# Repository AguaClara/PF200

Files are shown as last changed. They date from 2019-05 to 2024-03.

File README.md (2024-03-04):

# Prefabricated-Pilot-Plant
Working on optimizing and redesigning the PF300 Plant.

[Data: constantly updated during plant operation](https://drive.google.com/drive/folders/15Q-oahdi-_HOuTjkzV-ZeO8t-d6P-ldm?usp=sharing)

[OnShape](https://cad.onshape.com/documents/c2d1f86405270e814e117305/w/5a99281e258edb48b9d633f5/e/6bae3d77db5722cca1e4684c)

**Spring 2024 Team**

Jiaming Yuan jy729@cornell.edu

Ari Schor aes392@cornell.edu

Anjali Asthagiri aa2549@cornell.edu

Claire Wang cyw34@cornell.edu

**Fall 2023 Team**

Sarah Bae ssb238@cornell.edu

Joshua Luoma jjl364@cornell.edu

Kayla Stephenson ks929@cornell.edu

Ari Schor aes392@cornell.edu

Jiaming Yuan jy729@cornell.edu

Anjali Asthagiri aa2549@cornell.edu

[Fall 2023 Report](https://docs.google.com/document/d/e/2PACX-1vT9NayLwSj0DSO6I6zIm8iFLQtal2snJDCT8Y99-VTBxyXMKy_upGpKFzNsSaJLsYfuqjPXhcydjL0X/pub)

**Summer 2022 Team**

Isabel Crovella isc25@cornell.edu

Sarah Bae ssb238@cornell.edu

[Summer 2022 Report](https://github.com/AguaClara/PF200/blob/5bb9a7f38fa5151b12aef5d702b937e5a5cea816/PF200_Summer_2022_Final_Draft.ipynb)

**Spring 2021 Team**

Sandra Cangelosi sc2749@cornell.edu

Son-Jay Lake svl24@cornell.edu

Melissa Louie ml897@cornell.edu

Lynn Shin ms3244@cornell.edu

[Spring 2021 Report](https://github.com/AguaClara/PF200/blob/master/Spring%202021/PF200_Report_Spring_2021.ipynb)

**Spring 2020 Team**

Whitney Denison wwd23@cornell.edu

Ashley Zeng az342@cornell.edu

Sandra Cangelosi sc2749@cornell.edu

**Fall 2019 Team:**
[Mid-semester Symposium Presentation](https://docs.google.com/presentation/d/1beXxfFk0Zb6vNhiRZd7WTKsvpil8FLFxB8vfp_9dHnY/edit?usp=sharing)

**Summer 2019 Team:**

Marcin Sawczuk mas874@cornell.edu

Kevin Sarmiento ks2255@cornell.edu

Ian Cullings idc25@cornell.edu

Yitzy Rosenberg yyr2@cornell.edu

[Symposium Presentation](https://docs.google.com/presentation/d/14-7EX47XN8-9KOKcPPQAOfRzo7gDOhDvY8mLLPdoe-Y/edit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)

[Final Presentation](https://docs.google.com/presentation/d/1NT3kG8-FQKytqtTQstRGDQaPQnel-frj4UgSt9LlMlI/edit?usp=sharing)

[Final Report](https://colab.research.google.com/github/AguaClara/Prefabricated-Pilot-Plant/blob/master/Summer2019_Report_2.ipynb)

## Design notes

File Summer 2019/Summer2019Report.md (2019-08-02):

sedimentationweir# Prefabricated Pilot Plant, Summer 2019
#### Ian Cullings, Yitzy Rosenburg, Marcin Sawczuk, Kevin Sarmiento
#### August 2nd, 2019

##Abstract

The AguaClara PF 300 is a fully functional small scale water treatment system currently utilized in Honduras.  It's smaller scale makes it ideal for villages where the need is still significant, but it is not economical to build full scale built plants.  While the plant currently operates, there are significant problems in the design which need to be resolved to further improve treatment and allow for more to be built.  Additionally, the PF 300 serves as a perfect model for typical water treatment processes, including flocculation, sedimentation, and filtration, and thus data collected from this system can be used to study these processes and inform future design decisions.  The goal of the team this summer is twofold: collect water quality data from the plant, and use this information on new design projects for the system.  

## Introduction

The AguaClara PF 300 system (previously known and the 1 LPS plant or the Plantita) is a small scale, built system which can treat water at a rate up to 0.66 L/s.  The system was designed using AguaClara's principles, and thus models the built water treatment plant in the key areas:
* Gravity Powered: The entire plant is entirely powered from differences in hydraulic head from the inlet and outlet.  The design does not utilize electricity or mechanical parts, pieces that cause many problems when utilized in the field
* Built in place: The plant does not use any moving parts, and thus is functional from installation, reducing needs for maintenance and extending the operational life
* Utilizes hydraulic flocculators: Similar to AguaClara's built in place plants the PF300 uses a hydraulic flocculator to obtain the desired collision potentials for efficient flocculation
* Floc Blanket technology: The sedimentation tank of the PF300 creates an effective floc blanket just like the built in place AguaClara plants
* Stacked Rapid Sand Filters: The PF300 has a similar stacked filter design to that of built in place plants with the distinction that filter in this case is enclosed and must be under negative pressure

The main objectives for the summer were:
* Restore PF 300 to full operation and install Stacked Rapid Sand Filter
* Install lab bench and computer and connect all sensors for data collection
* Redesign of PF 300 components to improve operation quality and make construction easier

## Literature Review and Previous Work

The first PF 300 system was designed during Spring 2016 and built during Summer 2016 by a group of students and engineers on Cornell's campus.  Future teams tested the system and worked to streamline the fabrication process, after which the first system was sent of Honduras for testing in the field.  In 2017 another system was fabricated at Cornell and tested with the full treatment process, which continued into Spring 2018.  

In Fall 2018, there was no subteam specifically focused on research with the PF300.  Instead, Meng student Zoe Maisel focused her thesis on developing the PF300 system for usage in the United States.  Part of her project was moving the PF300 system from the DeFrees Hydraulic Lab at Cornell to the Cornell Water Treatment Plant.  There it was connected to the plants influent line, allowing for parallel operation of both systems for comparison.  She also wrote a detailed thesis comparing the PF300 system with typical water treatment systems within the US [(Maisel, 2018)](https://github.com/AguaClara/Prefabricated-Pilot-Plant/blob/master/Lit_Review/Maisel-High_Rate_Processes.pdf).

As part of the CEE 3520 course at Cornell, a few student groups developed design projects around the PF 300 which formed the basis for the design work this summer.  Inspiration for the plastic honeycomb piece for plate settlers came from "TuBe Or Not TuBe: A Comparison of Alternative Plate and Tube Settler Geometries" [(Connely et. al. 2019)](https://github.com/AguaClara/CEE3520/blob/master/Previous%20Final%20Projects/2019S/HummusHummus_Final_Report.md).  The design idea and code was sourced from the "Flocculatorita" project [(Blahut et. al. 2019)](https://github.com/AguaClara/CEE3520/blob/master/Previous%20Final%20Projects/2019S/Flocculatorita.md).  And the redesign of the sedimentation tank was based on work done in "Straight singular sedimentation tank for a modular plant" [(Guardado et. al. 2019)](https://github.com/AguaClara/CEE3520/blob/master/Previous%20Final%20Projects/2019S/LaMeraChimba_4L_per_S_sed_tank.md).  

Research that inspired the current questions on particle removal was done by Casey Garland.[(Garland, 2016)](https://github.com/AguaClara/Prefabricated-Pilot-Plant/blob/master/Lit_Review/Garland%26Monroe_Failure_modes_of_a_floc_blanket.pdf) [(Garland, 2017)](https://github.com/AguaClara/Prefabricated-Pilot-Plant/blob/master/Lit_Review/Garland%26Monroe_revisiting_hydraulic_flocculator_design.pdf).

## Methods

# Project One: Sensors and Data Acquisition

The first project for the summer is installing a number of sensors to collect data on the effluent from the PF 300.  Five sensors were installed: two Chemtrac PC6 particle sensors, one Chemtrac UV254 organics sensor, and two HF Scientific Turbidimeters.  One turbidimeter, one particle counter, and the organics sensor take samples from the effluent of the sedimentation tank (known as settled water), and the other turbidimeter and particle counter take samples from the outlet to the filter box.

All five of these sensors are connected to a main computer on the lab bench through Modbus RS485.  Modbus allows connection to up to 255 different sensors, each with a differing address.  Therefore, the team was able to wire each sensor together in a "daisy chain," with one single wire going into from the HydroAct through an adapter and connected directly into the computer.  

Effluent quality data is logged directly with ProCoDa, a process control software developed by Dr. Weber-Shirk.  The method file for data collection is available [on Github](https://github.com/AguaClara/Prefabricated-Pilot-Plant/blob/master/Data/Method_Files/Plantita_2.pcm).  The code for this, written by Dr. Weber-Shirk, is very similar to that used in the lab to connect to the turbidimeters.  Each device is assigned an address in the network, and then each data input (for example, total particle count, or the UVA reading) is assigned a data address from that device.  ProCoDa constantly samples these and saves them into an excel datalog, which is then imported from that computer through google drive to the cloud.  [You can view the data in real time here!](https://drive.google.com/drive/folders/15Q-oahdi-_HOuTjkzV-ZeO8t-d6P-ldm?usp=sharing)

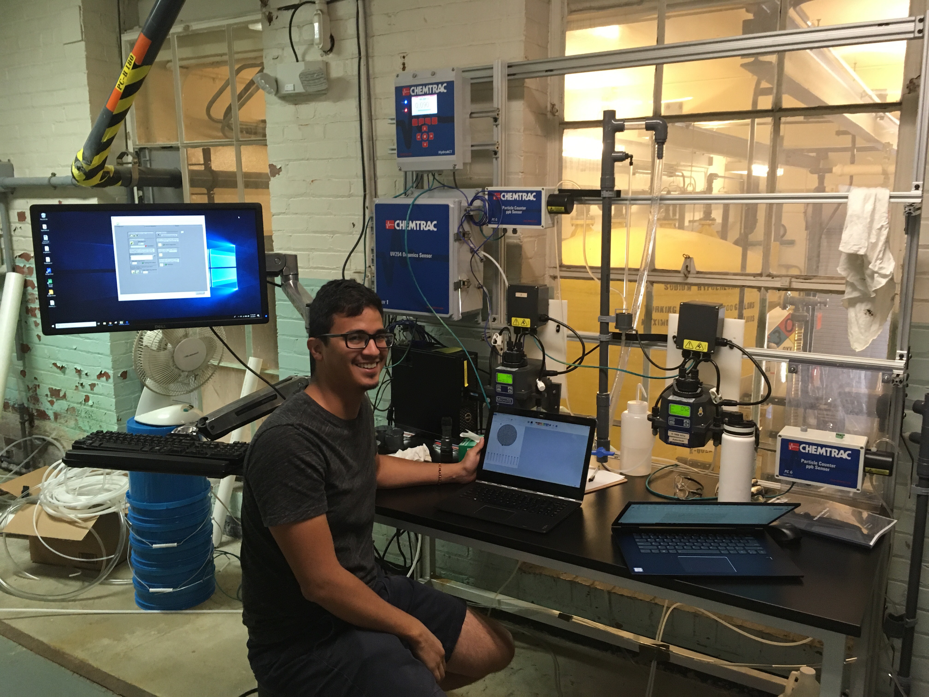
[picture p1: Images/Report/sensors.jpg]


**Figure 1:** The full sensor setup at the lab bench

This data will be used for two purposes.  The first is to further research on floc blanket function and efficiency.  Past research by Casey Garland showed that particle removal efficiency of the floc blanket was first order with respect to depth, but then eventually tapered off to a flat line with no further particle removal.  [This video](https://github.com/AguaClara/Prefabricated-Pilot-Plant/blob/master/Lit_Review/sedimentation.mp4) shows one experiment that gave this result.  This information is part of the justification for the design floc blanket height.  However, current theories in particle interactions within floc blankets suggest that smaller particles are being preferentially removed from the floc blanket, while larger particles become more easily sheared off and escape.  In an upflow system like the floc blanket, there is a stagnation point under suspended particles.  If a smaller particle follows the streamline and hits this point, it can easily collide and stick to this particle.  However, if a particle follows another streamline, the boundary layer around the particle prevents collisions.  This rapid flow around the particles also can shear larger particles off and allow them to escape.  This is shown in Figure 2 below.  

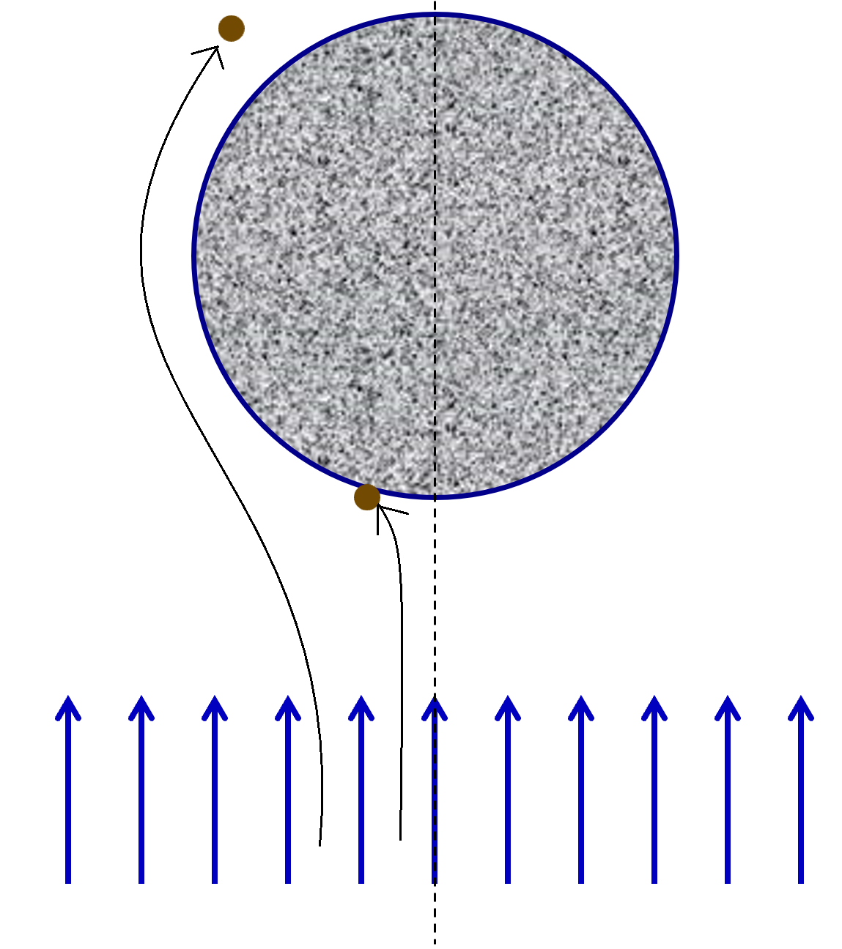
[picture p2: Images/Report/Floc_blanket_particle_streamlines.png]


 **Figure 2:** The large floc is suspended in the floc blanket and has a point of stagnation that allows smaller primary particles to effectively collide if their approach is from the correct orientation, streamline on the right. However if the particle is too far off the side then a collision will not occur, left most streamline.

Since turbidimeters are unable to measure turbidity from small particles well (since they reflect significantly less light than larger ones) it is possible that previous experiments did not capture this result well.  Thus, data collection on particle size distributions will provide a more accurate picture of the types of particles escaping the floc blanket.

If this theory is true, it suggests that increasing the height of the floc blanket will actually be beneficial, as smaller particle removal will increase.  Since these particles are very difficult to remove, even within the filter, this result would be very positive towards increasing the treatment capability of AguaClara plants of all scales.

The other important parameter to collect for this experiment is the height of the floc blanket.  Unfortunately, since the PF 300 system is not transparent, there is no way to visually inspect this.  The only directly visible measure is through the floc hopper, where flocs can be seen escaping.  This only occurs when the floc blanket begins to grow above the height of the floc hopper (the maximum height).

The team considered a number of possible sensors to detect height as a function of time, including installing electrical sensors inside, taking constant measurements from the sampling ports on the side of the plant, and taking measurements by lowering a probe in from the top of the plant.  All of these possibilities were eventually decided against, and the following methods were determined to be the most simple and effective:

1. Experiments with a typical rangefinder, pictured below, show that it can read the height from the top of the floc blanket.  Thus, by continuously running a rangefinder affixed to the top of the plant, and shining the laser between the plate settler, we can measure the distance from the rangefinder to the top of the floc blanket, and using simple geometry we can convert this into the height of the floc blanket.  The current rangefinder in use works but does not connect to a computer, so measurements must be made manually.  Note that the rangefinder doesn't work if water is too turbid that the particles reflect the laser, but the team found that typically within ~30 minutes after startup turbidity lowered enough to make accurate measurements.

2. When the plant begins operation after being fully drained, the floc blanket height can be assumed to be 0.  Once significant levels of flocs are observed leaving the floc hopper, the floc blanket can be assumed to have reached it's maximum height.  In between, the relationship between floc blanket height can be approximated as linear.  By measuring the time flocs begin to leave the floc hopper, the slope of this line can be determined.

Research is ongoing into the best method to measure this.

The second purpose for data collection is to provide water quality data over long term usage of the PF 300, which can justify the efficacy of the system, and provide direct comparison with other conventional water treatment systems like the Cornell Water Filtration Plant.  While PF 300 systems are currently only utilized in Honduras, there is lots of evidence that a similar system would be very useful in smaller communities in the United States, or other areas.  One such example is Native American reservations, which have had many issues with water quality and supply in the past.  Team members have talked with officials from the US Indian Public Health Service and are beginning to explore the need for these systems there.

# Project Two: Filter Assembly

Previous teams designed and built the Enclosed Stack Rapid Sand Filter and transported it to the Cornell Water Filtration Plant. This summer the team worked to connect it to the PF300 and make the necessary changes to ensure that it operates.

## Assembly

The first task to connecting the filter was to find a way to divert the settled water to the filters entrance tank. The sedimentation tank's effluent leaves through a 3 inch PVC pipe that then is diverted to the CWFT's rapid mix unit for treatment. This technique allows us to run our experiments with the same water that the CWFP uses and also ensures that our experiments won't compromise the CWFP's treated water quality. A tee and two ball valves were installed on the sedimentation tank's exit line to allow the settled water to be selectively diverted either to the filter or to waste.
In addition to that change we took the opportunity to add a flow weir to the sedimentation tank. This allowed us to raise the water level inside of the sedimentation tank and ensure that the exit launder was fully submerged at all times with about an inch of water above it.

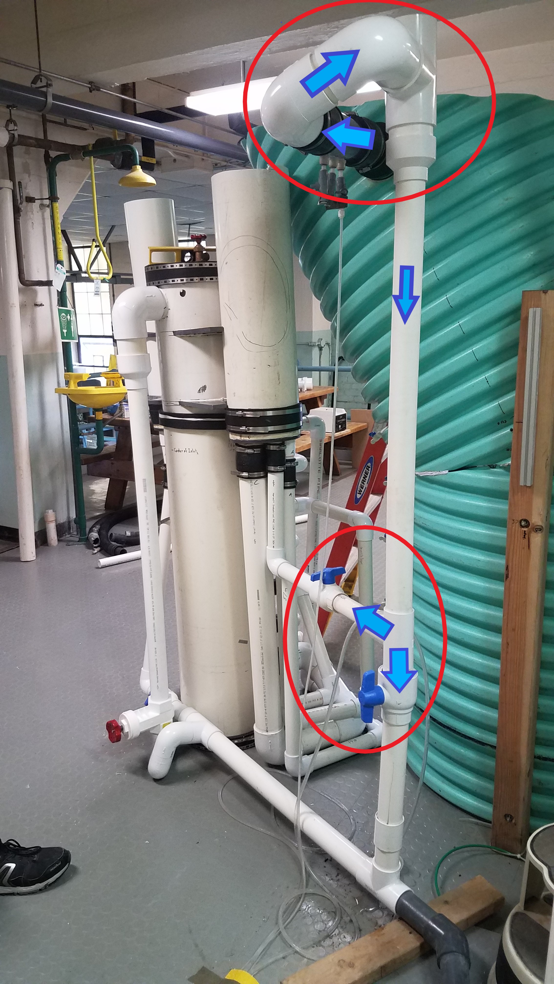
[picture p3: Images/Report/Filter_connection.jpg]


**Figure 3:** The flow weir was made out of two 3 inch PVC elbows and can be seen in the top circle. The settled water flows down the main pipe and can be diverted either to the filter, to the left, or to waste, straight down.

As can see in figure 2, when the ball valve in the vertical pipe is closed and the valve in the line feeding the filter is opened, settled water will go through the filter and be treated further.

## Filter Entrance Tank

Settled water from the sedimentation tank first arrives to the entrance tank of the filter, right most tank in figure 3.

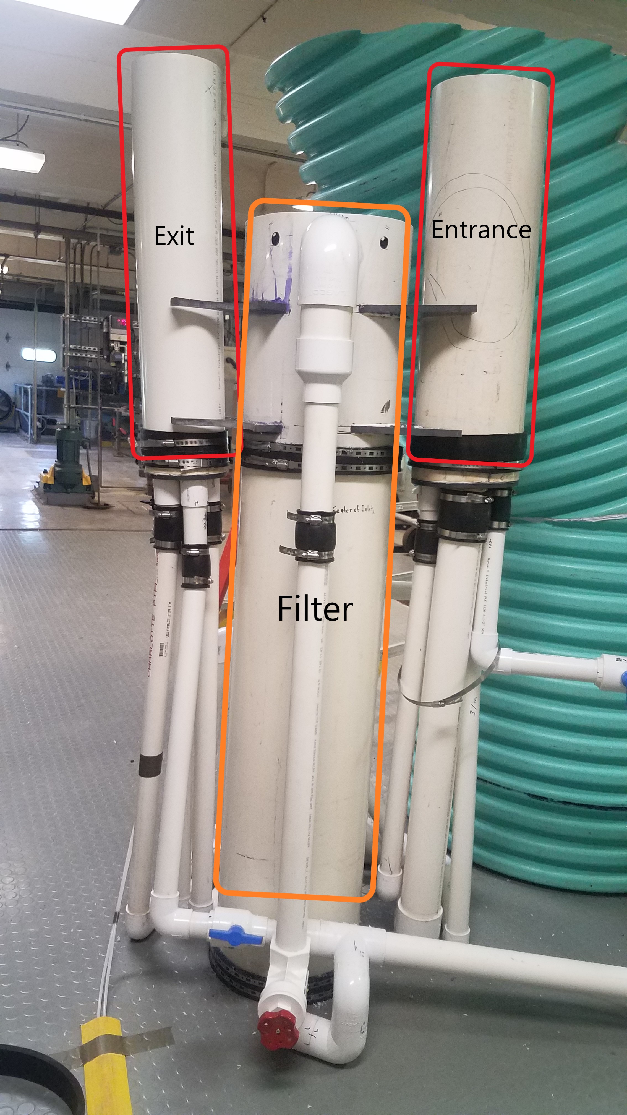
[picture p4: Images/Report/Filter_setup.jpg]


**Figure 4:** The three main compartments of the filter are the entrance tank, sand filter body, and effluent tank.

Once the settled water enters the tank, the flow gets divided into four separate PVC pipes which feed the filter at four different elevations. The distribution of flow can be seen in figure 5. Additionally, the entrance tank has 16.5 cm pipe stubs on three of the four pipes leading to the filter. This allows the entrance tank to function properly during filtration and also during backwash. During filtration settled water needs to go through all of the pipes, therefore the water level in the entrance tank needs to be high enough to allow flow into the pipe stubs. However, during backwash the flow needs to go through the larger diameter pipe, labeled in red in figure 4. This pipe attaches at the lowest point in the filter tank and because of that is responsible for fluidizing all of the sand in the tank during the backwash process. The pipe stubs ensures us that during backwash all of the flow goes through the bottom most pipe.

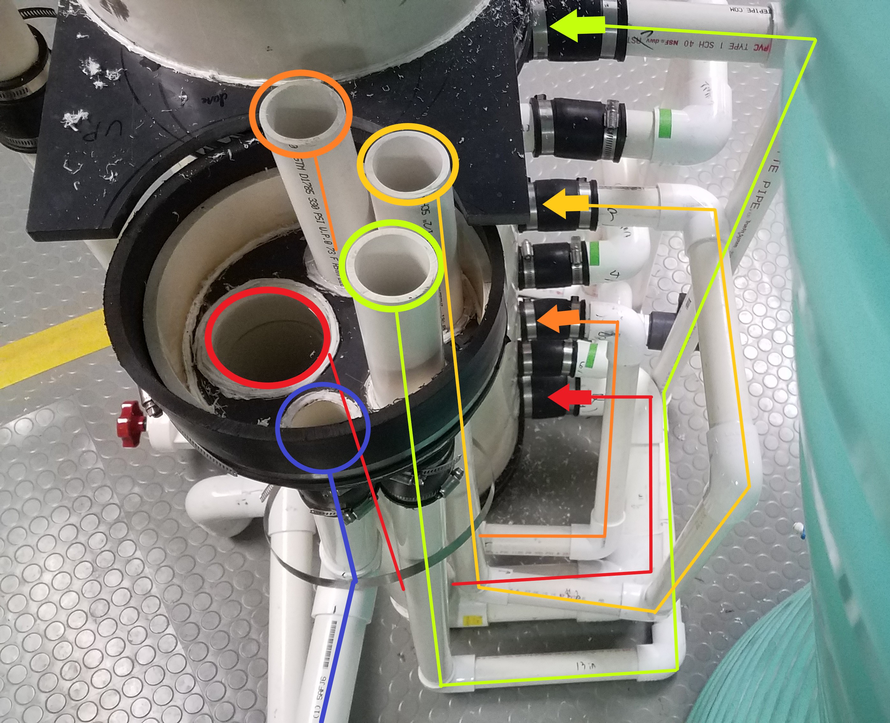
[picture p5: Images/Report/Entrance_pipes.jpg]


**Figure 5:**  Flow directions through the inlet pipes within the filter.

# Project Three: System Redesigns

## Flocculator

## Sedimentation tank

## Filter

This summer was the first time a EStars filter had ever been fully assembled and tested in a treatment process.  As with any complicated system, there were numerous problems that come up, and further design and testing is needed before this system can be implemented in the field.  The major problem identified with this system was the escape of sand through influent and influent pipes.

Escape of sand through the influent pipes was observed many times during operation, often due to errors in running the system.  The filter is designed such that sand should never escape the inner tank, as the upflow velocity should be too low to lift the particles all the way out the siphon system.  The following processes showed loss of sand (either through the siphon to effluent, or into the influent pipes):

* Running backwash without first opening the effluent line.  Backwash is a very fine balance of pressures, and if one side is over or underpressurized it will not work properly.  Thus it is very important that whenever backwash is run the effluent line is open throughout the entire process.
* Closing the backwash value quickly.  When backwash is running, water is flowing through the siphon very quickly due to the negative pressure.  If you close the valve and stop this process too quickly, it can "shock" the system and cause water to flow backwards through the pipes to return to the static head.  When ending backwash you must close this valve very slowly and gradually, at roughly 1 turn every 10 seconds.
* Opening flow into the filter without stopping flow to effluent.  There are two valves at the junction after settled water, one controls flow to the drain, and one controls flow into the entrance tank of the filter.  Typical operation is to open flow to the filter first then stop flow to drain, to prevent flooding.  However is the influent tank is left full of water, this water will flow backwards to lower head when the valve is open, which can pull sand from the inner tank.  Thus, whenever you reconnect the filter you must first close the valve to drain, allow water to rise to about the level in the entrance tank, then open the valve to the entrance tank.  

The team also observed significant amounts of sand within the exit tank, and even some in the turbidimeter reading from the exit tank. This means that sand is escaping the inner tank to effluent, which the slotted outlet pipes are designed to prevent.  This suggests that some of all of the slotted outlet pipes were designed incorrectly, and that sand can escape through these pipes.  

While a few different possibilities were considered, this shows a clear failure in the filter, and means that the filter must be either be repaired or remade completely.  Work is ongoing, but the current plan is to assemble a new filter, using the design of "gravity exclusion zones" by [Stars FINE](https://github.com/AguaClara/StaRSFine) in Spring 2019.

# Operation Manual

To turn the PF 300 on and begin collecting data:

1. Ensure all valves are open and flow is not blocked anywhere
2. Turn the main pump switch from OFF to HAND to begin flow within the plant
3. Turn on the peristaltic pump on the floc hopper and ensure the valve coming off the floc hopper is opened
4. Turn on the HydroAct and both turbidimeters by plugging them in
5. Turn on the main computer on the lab bench and log in on the generic AguaClara account, en-ce-ac
6. Open ProCoDa and check that the "Plantita_2" method file is being read
7. Data will automatically be collected and saved by ProCoDa, and uploaded into the cloud by Google Drive

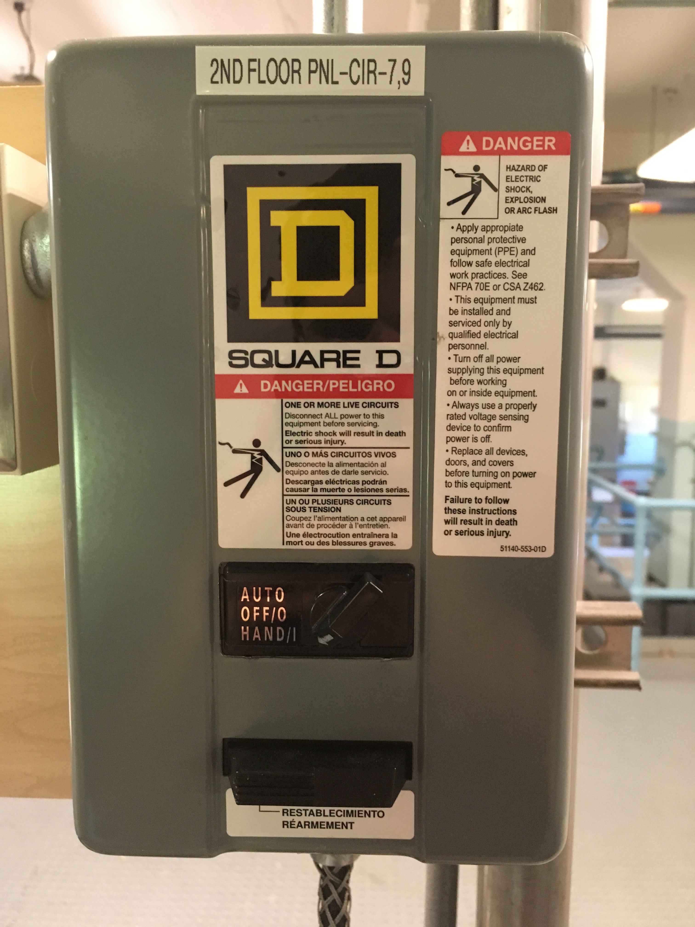
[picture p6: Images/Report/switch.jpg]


**Figure 6:** ON/OFF switch for the pump

To pressurize the filter (necessary whenever there is air within the inner tank, such as after removing the lid for repairs):

1. Open the valve on top of the filter to allow air to escape during process
2. Close the outlet valve to ensure no flow is leaving the filter
3. Water will begin to flood and raise the level within the influent tank.  Wait until water comes out of the top valve of the influent tank, then quickly close the top valve and open the effluent.  
4. Sometimes due to the flow restrictions by the sand bed, water level will rapidly rise in the entrance tank but will not raise in the inner tank for a while.  In this case open the valve off the effluent from the sedimentation tank partially to prevent the entrance tank from overflowing, and wait until water leaves the top valve of the inner tank
5. When you open the effluent you should hear a gurgling sound and observe flow being pulled into the effluent pipe.  This means the inner tank is pressurized and filter is operating correctly

To run backwash in the filter:

1. Backwash should be run whenever headloss in the entrance tank causes water level to rise significantly, typically daily.  Whenever you change the sand within the tank, you should also run backwash first to remove any particles that may have built up
2. Ensure inner tank is pressurized and there isn't air inside
3. Open the red backwash valve.  You should hear water being pulled through this pipe to the drain
4. Ensure that water level in the influent tank drop to below the pipe stubs on the entrances to the other inlets.  When backwash is operating fully, water should only be flowing from the backwash line
5. After backwash is complete, **slowly** close the backwash valve.  Once the valve is completely closed backwash should end and filter operation should resume as normal.

To flush pipes (cleaning sand from within):

1. Insert pipe plugs on all pipes except backwash line
2. Start backwash cycle as normal.  Run with just backwash line for 1-2 minutes
3. Open plug for lowest influent line (leftmost pipe).  Plug backwash line and allow water level to rise
4. If the water level is too low (just above the pipe stub) air will also be sucked in through the line.  To prevent this, partially block the pipe stub and allow water level to raise ~6 inches above the pipe stub entrance.  We used our fingers to block this, although this is not recommended as the suction is very strong.  
5. Swap the plugs and repeat this process for the other two pipes.  Whenever you switch flows ensure water level is high enough that air doesn't enter the pipes
6. Once you have flushed all pipes break backwash and remove all plugs.  If sand was removed from the pipe the sand level should be observably higher

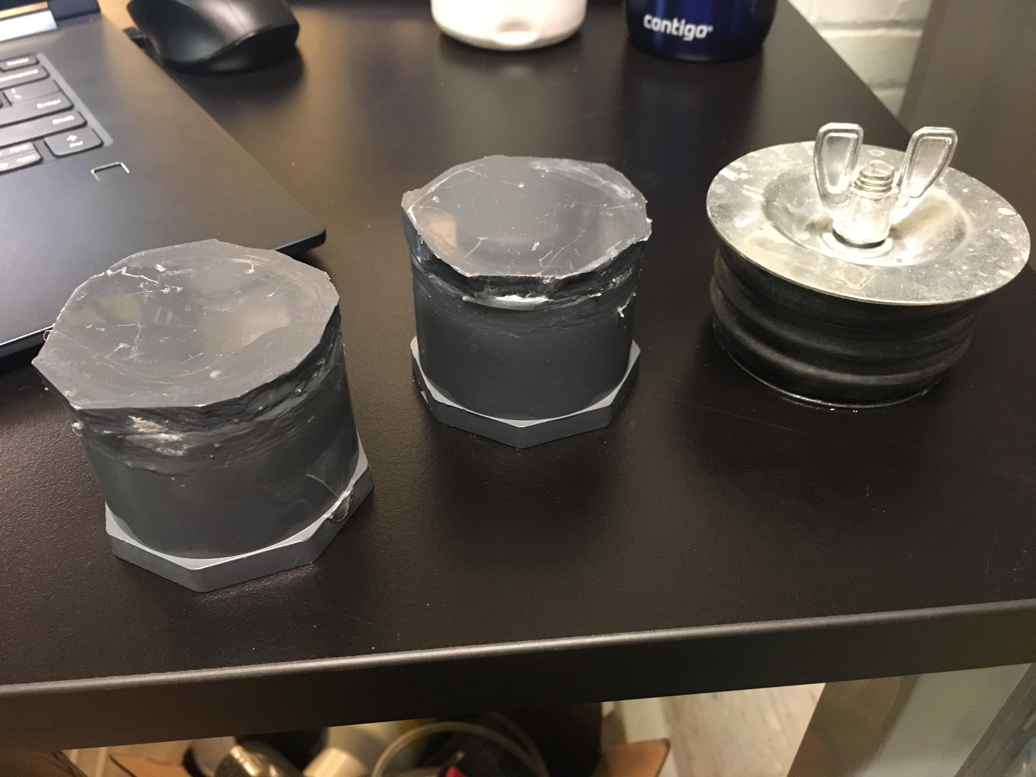
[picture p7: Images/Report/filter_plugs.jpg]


**Figure 7:** Plugs used to force flow through one inlet

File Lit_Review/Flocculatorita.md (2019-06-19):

#The Flocculatorita

####By The Water Tzars: Nina Blahut, Lily Falk, Marcin Sawczuk, Yitzy Bitzyspider


<p align="center">

*Figure :). Floco, the flocculatorita mascot.*

## Introduction and Background

The prefabricated plants (PF300) are a subset of AguaClara plants designed for small communities who may not have the resources to finance, or the population to require a built-in-place plant. There are currently 3 in Manzaragua, 1 in Cuatro Comunidades, 1 near Copan (Honduras) in use, and one at Cornell's Water Filtration Plant in the testing phase. Built-in-place AguaClara plants are housed in buildings with separate areas for flocculation, sedimentation and filtration. In contrast, the PF300 occupy considerably less space, as the plant is only two and a half meters tall.

PF300 plants have made it possible for small communities to receive clean water, and have served as an addition to increase the capacity of built-in-place AguaClara plants, as they were added in parallel with the main treatment process chain.

The low population density and small community size in areas that use PF300 plants has led to difficulty with employing plant operators. The PF300 plants provide water to fewer people, however require the same degree of monitoring as a full scale plant. As a result, delegating a plant operator has created a larger burden on these communities. An ideal system for an individual to check on the plant for coagulant dosing and general running issues has not yet been well established.

The PF300 flocculator is in need of improvement to increase flexibility of the design. Currently the flocculators are made out of 3" PVC pipe. High cost of the PVC fittings make it expensive to build flocculators according to this design for higher flow rates or residence times. This is because the change would require switching to bigger pipe diameters. Representatives from AguaClara’s partner organization in Honduras, Agua Para El Pueblo (APP), have expressed interest in a larger flocculator. A longer residence time would provide operators with more time to respond to high turbidity events to prevent the dirty water from reaching the sed-tank and disturbing the floc blanket which causes long term decrease of the effluent water quality. Moving forward, there is desire for the portable plants to come in multiple sizes. Hopefully, this would lead to a more cost efficient design of the prefabricated plants in various sizes.

The Water Tzars have worked to design a new flocculator which will be more flexible and scalable than the current system. The group has envisioned flocculation within a large diameter pipe divided into channel with baffles and expansions enabling complex flow within the pipe that would lead to successful floc formation. Moving forward the group will consider alternative materials for the sheets that will work as baffles.


<p align="center">

*Figure 1. Sample Flocculatorita design.*

## Design Process

The design process for the small hydraulic flocculator is based on the AguaClara top down design approach (presentation 2, slide 20), but made slight alterations to make it possible for our flocculator to fit into a large PVC pipe or HDPE tank. We then modified the AguaClara Flocculator source code to come up with a class that designs a small flocculator that can be housed inside of a large PVC pipe, which we have named a "flocculatorita". The collision potential ($G_{CS} \theta$) for our design is constrained to 37,000, which is based on the collision potential that is currently used in AguaClara plants (2). Our design is also constrained to a total headloss of 40 cm. This constraint is also based on the head loss which is currently used in AguaClara flocculators (3). Next, the height of the flocculator is constrained to 2 meters. This is to ensure that the flocculatorita is not taller than a sedimentation tank. This logic is also borrowed from AguaClara source code (3). Lastly, our design is constrained by the available diameters of large PVC pipes that can be used as a tank for our flocculatorita.

The first step in AguaClara's top down design approach for the flocculator is to calculate the required flocculator volume. We used the same process as defined in the AguaClara Flocculator source code to determine the required active volume in our flocculator (3). To do so, the AguaClara flocculator class first calculates the Camp Stein velocity gradient (average velocity gradient) using the following equation:

$G_{CS} = {\frac{gh_{\rm{L}}}{\nu G\theta}}$

This calculation is done below in the property "vel_grad_avg." Then, the average velocity gradient is used to calculate required residence time in the flocculator by dividng [spelling] target collision potential by the calculated average velocity gradient:

 $\theta = {\frac{ G\theta}{G_{CS}}}$

  This calculation is carried out in the property "retention_time." Finally, the calculated retention time and user-defined flow rate is used to determine the required flocculator volume (calculation is performed in the class "vol"):

$\rlap{-} V_{floc} = {\theta}{Q}$

After calculating the necessary active volume in our flocculatorita, we determined the necessary active cross sectional area by dividing the volume by the height of the flocculator:

$A=  \rlap{-} V_{floc}/ H_{floc}$

We made some simplifying assumptions to decide which size PVC pipe was appropriate to use as a tank for the flocculatorita. We assumed that the active space inside of our tank would be the largest square that could be housed in a cross section of the PVC pipe tank, to avoid the complication of different sized/shaped flow channels. This simplifying assumption results in excess dead volume, but we hope in the future to come up with an algorithm to optimize the cross sectional area of the pipe to minimize that dead volume. Using our simplifying assumption, we found the side length of the largest square, and used Pythagorean's Theorem to find the length of the diagonal of the square. This length is the necessary diameter of the PVC pipe tank:

$D_{tank}=\sqrt{2*A}$


<p align="center">

*Figure 2. Top view showing the original design idea. This design was based on a square active area housed within the circular PVC pipe.*

These calculations are carried out in the property "min_diameter_tank." Then, the code selects the PVC pipe diameter that is closest to and larger than the calculated minimum from an input array of available PVC pipe diameters in the property "design diameter tank."

After selecting a PVC pipe to use as a tank, we solved for the side length of the square that would fit inside of the chosen pipe using the Pythagorean Theorem:

$L=\sqrt{\frac{1}{2}D_{tank}^2}$

This calculation is performed in the property "channel_L" because the length of one side of our square is analogous to the channel length in a regular AguaClara flocculator.


<p align="center">

*Figure 3. Top view showing example channels
 (three chosen for picture arbitrarily).*

The next step was to determine baffle spacing and channel width. Since there was not a clear constraint on either, we decided that we would allow the user to input the number of channels, and use that to determine channel width:

 $W_{channel}=L_{channel}/n_{channel}$

 A benefit to this method is that it creates channels with equal widths and maximizes the space used within the square cross section of active space. This calculation is included in the property "channel_W."

 
 <p align="center">

 *Figure 4. Top view with channels and baffles (number of each chosen arbitrarily for drawing).*

Next, we used the AguaClara source code to determine the maximum distance between expansions for the largest allowable H/S ratio (3). The equation used in that calculation is:

$H_{e_{Max}} = \left[ \frac{K}{2 \nu G_{CS}^2} \left( \frac{Q \Pi_{{HS}_{Max}}}{W_{channel}} \right)^3 \right]^\frac{1}{4}$

Next, we determined the number of flow expansions per baffle space with the calculation (2):

$n_{expansions} = {\rm ceil}\left( \frac{H}{H_{e_{Max}}} \right)$

This calculation used included in the property "expansion_n".

Our next step was to determine the baffle spacing. We did so using the AguaClara source code. The property is named "baffle_S" and it calculates baffle spacing using the equation:

$S = \left( \frac{K}{2 H_e G_{CS}^2 \nu } \right)^\frac{1}{3} \frac{Q}{W_{channel}}$

The next property in the Floccuratorita class determines the number of obstacles per baffle. This is done using the AguaClara source code, and it is simply one less than the number of expansions per baffle space, since one expansion is taken care of with the 180 degree bend (3).

The next property, "obstacle_size" determines the size of the obstacles, so that the energy dissipation rate for flow expansions caused by the obstacles and the 180 degree bends are equal. The Vena Contracta for a 180 degree bend is approximately 0.384 (presentation 1, slide 7), so we solved for the obstacle length, given the baffle spacing that would result in the same Vena Contracta:

 $L_{obstacle}=S_{baffle}(1-\Pi_{VC})$

 We plan to fabricate these obstacles using half pipes.

Then, the property "baffle_n" calculates the number of baffles:

 $n_{baffle}=\frac{L_{channel}n_{channels}}{S_{baffle}}$

 For the cost comparison, we are including the following factors:
 1. Cost of the main tank
 2. Cost of the sheets dividing the tank into channels
 3. Cost of the baffles
 4. Cost of the half-pipes used as obstacles for the flow

We also included a property called "pi_sedtank_floc," which calculates the ratio of the sed tank diameter to the flocculatorita diameter if the sed tank's up flow velocity is 1 mm/s and height is 2 m. According to the conservation of mass, the flow exiting the flocculator must equal the flow going through the sed tank, which is equal to the cross sectional area of the sed tank times its upflow velocity. Therefore,

$A_{sedtank}=Q/V_{up}$

"Pi_sedtank_floc" uses that relationship to find the cross sectional area of the sed tank and then uses that to find the diameter of the sed tank. Finally, it divides the diameter of the flocculatorita by the diameter of the sed tank and returns that ratio. This function does not account for the fact that diameters are only available in discrete sizes.

## Cost Comparison
First, we decided to model a floculatorita that has a residence time of 1 minute and flow rate of 1 liter/second in order to make a reasonable cost comparison between our design for the flocculatorita and the current flocculator used for the PF300 plant. We did so by making a child class of the "flocculatorita" class with those adjustments. This child class is named "Floc_1_min_res" and is shown in the block of code below. Next, we used that class to get an estimate of the cost of the floculatorita, which would handle similar flow and have the same collision potential as the current PF300 flocculator.

### Cost Comparison Analysis

Based on our cost comparison, the flocculatorita is 1.606 dimensionless times the cost of the current flocculator. That being said, this estimate is an overestimate due to the fact that it utilizes US prices more than Honduran prices. Even with the additional price, the new design presents improvement over the old as it is more adaptable, and has potential moving forward.

# Future Work

### Adding the auxiliary equipment
Current design of the flocculator does not include the auxiliary components or manufacturing procedures. To make the design suitable for commercial deployment, it should include the following aspects:

  1. Method for fixing the PVC sheets to the wall of the tank. We propose using long pieces of PVC glued to the inside of the tank wall, which will create a slot for sliding in the PVC sheet. The slot could be then filled with the silicone gasket maker, in order to seal the connection.

  2. Tank bottom design, preferably allowing for disassembly for servicing. Tank should have a flat bottom, which will be supported by the concrete floor. Although it requires placing the flocculator inside the structures with a solid floor, the advantage of having a support structure beneath the tank and therefore not having to worry about supporting the water mass by the tank bottom exceeds potential complications. Flat bottom of the tank can be attached to the corrugated pipe using clamps or bolts holding onto the pipe corrugations. Bottom should be fitting with the slots similar to the ones on the walls, in order to ensure sealed connection with the PVC sheets. Silicone gasket maker can be also used for sealing the connection between the pipe and the bottom.

  3. Attaching an entrance tank/rapid mix unit and a chemical dosing system. In the current PF 300 design, rapid mix and the dosing system are separate units. However, in order to fully take advantage of the compact design proposed in this project, it might be beneficial to incorporate both of them in the flocculator structure. This way, the plant layout will become simpler and more robust, as the components will be protected from impact by the outer structure of the corrugated pipe. Moreover, the pipe itself will provide sufficient structural support for mounting the entrance tank a the chemical dosing system, without the need for additional structure.

  4. Connection to the sedimentation tank, with a valve providing option for separating the two units and additional drain lines at both sides of the valve, in case of need for draining either the flocculator or the sed-tank. Connection should be made through the hole at the bottom of the flocculator tank.

  5. In order for 4. to work, water has to flow in an order which would allow for draining the flocculator after removing the baffles, i.e. connections between the channels separated by the PVC sheets has to be made at the bottom of each sheet (similar to the concrete AC flocculators)

  6. Drain line for wasting the water from the flocculator can be simply added by making a hole at the top of the last channel, above the water level in the first channel. Closing the connection between the flocculator and the sed tank will result with raising the water level until it reaches the drain line, from which it will be wasted.

  7. Baffles can be made in a similar way to the ones currently used, as packets of the polycarbonate sheets with the half-pipe flow constrictions, which can slide into the channels.

### Maximizing surface area

With our current design we only utilize roughly 64% of the available surface area in the tank. This obviously  is very inefficient from a design and cost perspective. As the current cost comparison demonstrates approximately a .6 increase using the flocculatorita design, if space could be maximized by extending the channels, at a minimum utilized surface area would increase to 84% and cost would decrease by .6, making the flocculatorita a comparable if not preferable design.

 $\%_{utilization}=\frac{A_{tank}-A_{flocculator}}{A_{tank}}*100\%$


<p align="center">

*Figure 5. Comparison of the current design and future work's wasted volume in tank.*

 For future work, the challenge would be to update the code in such a way that it maximizes the effective area used for flocculation. This will have to take into account, among others, the following considerations:

  1. The *geometry* required to get the target velocity profiles necessary for flocculation to occur. Assuming extension of the channels to the edge of the tank, consideration must be taken regarding the differences due to the curvature of the tank and how these differences effect the flow and subsequently the relating velocity profile. It is recommended that one err on the side lower velocity profiles in the uncertain regions to ensure that at the very worst, already created flocs don't break apart.


<p align="center">

*Figure 6. Illustration of uncertainty regarding effective geometry differences to get target flocculating velocity profiles.*

  2. The flow from one channel to another and then out of the flocculator needs to be designed. Consideration on to perhaps using the space in the wasted volume sections or using the ends of the channels where there is uncertainty about the flow geometry as the channel connections.

  3. The maximum angle given from the line created by tracing the first channel's uppermost tip to the last channel's lowermost tip and the first channel's line needs to be created taking into account wasted volume, usable flocculating compartments (that are dependent on target velocity geometries), channel connections, and inflow and outflow pipes.

### Cost comparison future work

The current cost estimate for the flocculatorita is likely much higher than the true cost to produce such a design. This is due to the fact that the costs are based on United States pricing, and materials in Honduras tend to be less expensive. Future work on this project must include price estimates from Honduras, or other countries that may employ the new design.

Furthermore, our design does not include the cost of the support structure for the baffles, cost of the fittings for connecting the rapid mix and the sedimentation tank, cost of the entrance tank and the cost of adjustments necessary for assembling the tank (such as fixing the PVC sheets to the pipe walls or construction of the tank bottom). Moreover, it does not include the cost of manpower.

In addition, the current price estimate is based on PVC sheets being used as baffles in the flocculator. In the future the team will work to discover a different material that can be used as baffles. This ideal material must be durable, less expensive than PVC sheets, and more appropriate for this application than the polycarbonate sheets used in other AguaClara plants.

##Flocculatorita Code

```python
import aguaclara.core.head_loss as minorloss
import aguaclara.design.human_access as ha
import aguaclara.core.physchem as pc
import aguaclara.core.pipes as pipes
from aguaclara.core.units import unit_registry as u
import numpy as np
import pandas as pd

BAFFLE_THICKNESS = 2 * u.mm
PVC_CHANNEL_THICKNESS = 1 * u.inch

class Flocculatorita:
    """Calculates physical dimensions of a flocculatorita
    ----------------------------
    - BAFFLE_K (K or K_{baffle}): float
        - The minor loss coefficient of the flocculator baffles.
    - CHANNEL_N_MIN (N_{channel}: int
        - The minimum number of flocculator channels.
    - HS_RATIO_MIN (\Pi_{HS}): float
        - The minimum ratio between expansion height and baffle spacing
    - RATIO_MAX_HS (\Pi_{HS}): float
        - The maximum ratio between expansion height and baffle spacing
    - SDR (sdr): float
        - The standard dimension ratio.
    """

    # Increased both to provide a safety margin on flocculator head loss and
    # to simultaneously scale back on the actual collision potential we are
    # trying to achieve.
    # Originally calculated to be 2.3 from the equations:

    BAFFLE_K = 2.5
    CHANNEL_N_MIN = 1
    RATIO_MAX_HS = 6.0
    SDR = 41.0
    pi_VC_180bend=.384 #source: (Floc Design PP )

    def __init__(
            self,
            Q=4 * u.L/u.s,
            temp=25 * u.degC,
            Gt=37000,
            HL = 40 * u.cm,
            downstream_H = 2 * u.m,
            ent_tank_L=0*u.m,
            max_W=42 * u.inch,
            available_tank_diameters = [12.2, 15.1, 18.2,24.1, 30.2,36.0,42.0,47.9,59.9,72.0],
            available_obstacle_diameters = [1/2,3/4,1,5/4,3/2,2,5/2,3,7/2,4,5,6,8,10,12,14,16],
            n_channels=5,
            pi_VC_180bend=pi_VC_180bend,
            tank_diameters_prices = [[12.2, 4.07], [15.1, 5.70], [18.2, 8.00],[24.1, 12.64], [30.2, 18.60],[36.0, 24.33], [42.0, 28.40],[47.9 , 39.42] , [59.9, 63.51]],
            baffle_price = (20.5/1872) * u.USD/(u.inch**2),
            PVC_channel_price = (431/4608) * u.USD/(u.inch**2),
            obstacle_diameters_prices = [[1/2, 1.95/5],[3/4, 2.35/5],[1, 3.91/5],[5/4, 4.55/5],[3/2, 4.99/5],[2, 6.90/5],[5/2, 10.26/5],[3, 13.90/5],[7/2, 39.95/5],[4, 18.90/5],[5, 57.50/5],[6, 37.94/5],[8, 55.00/5],[10, 76.81/5],[12, 109.86/5],[14, 180.75/5],[16, 228.52/5]]
            ):

        self.Q = Q
        self.temp = temp
        self.Gt = Gt
        self.HL = HL
        self.downstream_H = downstream_H
        self.ent_tank_L = ent_tank_L
        self.max_W = max_W
        self.n_channels=n_channels
        self.pi_VC_180bend=pi_VC_180bend
        self.available_tank_diameters=available_tank_diameters
        self.tank_diameters_prices = tank_diameters_prices
        self.baffle_price = baffle_price
        self.PVC_channel_price = PVC_channel_price
        self.obstacle_diameters_prices = obstacle_diameters_prices
        self.available_obstacle_diameters = available_obstacle_diameters

    @property
    def vel_grad_avg(self):
        #NOTE: this is borrowed from AguaClara source code
        """Calculate the average velocity gradient (G-bar) of water flowing
        through the flocculator.
        :returns: Average velocity gradient (G-bar)
        :rtype: float * 1 / second
        """
        return ((u.standard_gravity * self.HL) /
               (pc.viscosity_kinematic(self.temp) * self.Gt)).to(u.s ** -1)

    @property
    def retention_time(self):
        #NOTE: this is borrowed from AguaClara source code
        """Calculates the hydraulic retention time neglecting the volume created by head loss in the flocculator.
        :returns: Hydraulic retention time (:math:`\theta`)
        :rtype: float * second
        """
        return (self.Gt / self.vel_grad_avg).to(u.s)

    @property
    def vol(self):
        #NOTE: this is borrowed from AguaClara source code
        """Calculate the target volume (not counting the volume added by head loss) of the flocculator.
        :returns: Target volume
        :rtype: float * meter ** 3
        """
        return (self.Q * self.retention_time).to(u.m ** 3)

    @property
    def cross_sectional_area(self):
        """This function calculates the necessary active cross sectional area of the flocculator"""
        return (self.vol/self.downstream_H).to(u.m**2)

    @property
    def min_diameter_tank(self):
        """"this function calculates the necessary diameter to accommodate the required cross sectional area, assuming that the only "active space" in the cross section is the largest square that will fit into the larger PVC pipe"""
        return ((2*self.cross_sectional_area)**.5).to(u.inch)

    @property
    def design_diameter_tank(self):
        """This function selects the closest available PVC tank to the calculated minimum pipe diameter"""
        for i in range(len(self.available_tank_diameters)):
            if self.available_tank_diameters[i]*u.inch <= self.min_diameter_tank:
                i +=1
            else:
                return self.available_tank_diameters[i]*u.inch

    @property
    def channel_L(self):
        """This function determines channel length based the largest square that fits inside of the selected tank. So, channel length is the the length of the square"""
        return ((self.design_diameter_tank)**2/2)**.5

    @property
    def channel_W(self):
       """This function calculates the channel width by dividing the total width of the active cross sectional area by number of channels"""
       return (self.channel_L/self.n_channels).to(u.cm)
       ###NOTE: incorporate baffle width

    @property
    def expansion_max_H(self):
        #NOTE: This is borrowed from AguaClara source code
        """"Return the maximum distance between expansions for the largest
        allowable H/S ratio.
        :returns: Maximum expansion distance
        :rtype: float * meter
        Examples
        --------
        exp_dist_max(20*u.L/u.s, 40*u.cm, 37000, 25*u.degC, 2*u.m)
        0.375 meter
        """
        return (((self.BAFFLE_K / (2 * pc.viscosity_kinematic(self.temp) * (self.vel_grad_avg ** 2))) *
                (self.Q * self.RATIO_MAX_HS / self.channel_W) ** 3) ** (1/4)).to(u.m)

    @property
    def expansion_n(self):
        #NOTE: This is borrowed from AguaClara source code
        """Return the minimum number of expansions per baffle space.
        :returns: Minimum number of expansions/baffle space
        :rtype: int
        """
        return np.ceil(self.downstream_H / self.expansion_max_H)

    @property
    def expansion_H(self):
      #NOTE: This is borrowed from AguaClara source code#NOTE: This is borrowed from AguaClara source code
        """Returns the height between flow expansions.
        :returns: Height between flow expansions
        :rtype: float * centimeter
        """
        return (self.downstream_H / self.expansion_n).to(u.cm)

    @property
    def baffle_S(self):
      #NOTE: This is borrowed from AguaClara source code
        """Return the spacing between baffles.
        :returns: Spacing between baffles
        :rtype: int
        """
        return ((self.BAFFLE_K /
                ((2 * self.expansion_H * (self.vel_grad_avg ** 2) *
                 pc.viscosity_kinematic(self.temp))).to_base_units()) ** (1/3) *
               self.Q / self.channel_W).to(u.cm)

    @property
    def obstacle_n(self):
      #NOTE: This is borrowed from AguaClara source code
        """Return the number of obstacles per baffle.
        :returns: Number of obstacles per baffle
        :rtype: int
        """
        return self.expansion_n - 1

    @property
    def obstacle_size(self):
        """This function calculates the size of obstacles, so that the obstacles cause the same flow expansion as a 180 degree bend in the flocculatorita"""

        for i in range(len(self.available_obstacle_diameters)):
            if (self.baffle_S*(1-self.pi_VC_180bend)).to(u.inch) >= self.available_obstacle_diameters[i]/2*u.inch :
                i +=1
            else:
                return self.available_obstacle_diameters[i]*u.inch

    @property
    def baffle_n(self):
        """This function calclulates the number of the baffles in the flocculator."""
        return (np.ceil((self.channel_L/self.baffle_S*self.n_channels))).to(u.dimensionless)

    @property
    def design(self):
        """Returns the designed values.
        :returns: list of designed values (G, t, channel_W, obstacle_n)
        :rtype: int
        """
        floc_dict = {'n_channels': self.n_channels,
                     'channel_L': self.channel_L,
                     'channel_W': self.channel_W,
                     'baffle_S': self.baffle_S,
                     'obstacle_n': self.obstacle_n,
                     'G': self.vel_grad_avg,
                     't': self.retention_time,
                     'expansion_max_H': self.expansion_max_H,
                     'min_diameter_tank': self.min_diameter_tank,
                     'design_diameter_tank': self.design_diameter_tank}
        return floc_dict

    @property
    def cost_of_tank(self):
        """Returns the cost of the tank.
        """
        for i in range(len(self.available_tank_diameters)):
            if self.available_tank_diameters[i]*u.inch < self.design_diameter_tank:
                i +=1
            else:
                return (self.tank_diameters_prices[i][1]*(u.USD/u.ft) * (self.downstream_H + self.HL + 10*u.cm)).to(u.USD)

    @property
    def cost_of_baffles(self):
        """Returns the cost of the baffels.
        """

        return (self.channel_W * (self.downstream_H + self.HL + (10 * u.cm)) * self.baffle_n * self.n_channels * self.baffle_price).to(u.USD)

    @property
    def cost_of_PVC_channels(self):
        """Returns the cost of the PVC Channels.
        """
        return ((self.n_channels+1) * (self.downstream_H + self.HL + 10 * u.cm) * self.channel_L * self.PVC_channel_price).to(u.USD)

    @property
    def cost_of_obstacles(self):
        """Returns the cost of the obstacles.
        """
        for i in range(len(self.available_obstacle_diameters)):
          if self.available_obstacle_diameters[i]*u.inch < self.obstacle_size:
            i +=1
          else:
            return (self.obstacle_diameters_prices[i][1]*(u.USD/u.ft) * self.obstacle_n*self.baffle_n*self.n_channels*self.channel_W/2).to(u.USD)

    @property
    def total_cost(self):
        """Returns the cost total cost.
        """
        return self.cost_of_tank + self.cost_of_baffles + self.cost_of_PVC_channels + self.cost_of_obstacles

    @property
    def cost(self):
        """Returns costs of of everything
        """
        cost_dict = {'cost of tank':self.cost_of_tank,
                     'cost of baffles':self.cost_of_baffles,
                     'cost of PVC channels':self.cost_of_PVC_channels,
                     'cost of halfpipes':self.cost_of_obstacles,
                     'total cost':self.total_cost}
        return cost_dict

    @property
    def pi_sedtank_floc(self):
        """This function calculates the ratio of the sed tank diameter to the flocculator diameter if the sed tank's up flow velocity is 1 mm/s and height is 2 m"""
        up_V=1*u.mm/u.s
        depth=2*u.m
        A_sedtank=self.Q/up_V
        d_sedtank=(2*A_sedtank**.5).to(u.inch)
        return (d_sedtank/self.min_diameter_tank)

##make a data frame to show results
q  = 1 * u.L/u.s #change this flow rate in order to display design specs for the flocculatorita handling that flow rate
tester=Flocculatorita(Q=q)

data ={'':['Tank Pipe Diameter', 'Width of Channels', 'Baffle Spacing', 'Cost'],
       '1 Channel': [Flocculatorita(n_channels=1, Q=q).design_diameter_tank, Flocculatorita(n_channels=1, Q=q).channel_W, Flocculatorita(n_channels=1, Q=q).baffle_S,Flocculatorita(n_channels=1, Q=q).total_cost],
       '2 Channels': [Flocculatorita(n_channels=2, Q=q).design_diameter_tank, Flocculatorita(n_channels=2, Q=q).channel_W, Flocculatorita(n_channels=2, Q=q).baffle_S, Flocculatorita(n_channels=2, Q=q).total_cost],
       '3 Channels': [Flocculatorita(n_channels=3, Q=q).design_diameter_tank, Flocculatorita(n_channels=3, Q=q).channel_W, Flocculatorita(n_channels=3, Q=q).baffle_S,Flocculatorita(n_channels=3, Q=q).total_cost],
       '4 Channels':[Flocculatorita(n_channels=4, Q=q).design_diameter_tank, Flocculatorita(n_channels=4, Q=q).channel_W, Flocculatorita(n_channels=4, Q=q).baffle_S, Flocculatorita(n_channels=4, Q=q).total_cost],
       '5 Channels':[Flocculatorita(n_channels=5, Q=q).design_diameter_tank, Flocculatorita(n_channels=5, Q=q).channel_W, Flocculatorita(n_channels=5, Q=q).baffle_S, Flocculatorita(n_channels=5, Q=q).total_cost],
       '6 Channels':[Flocculatorita(n_channels=6, Q=q).design_diameter_tank, Flocculatorita(n_channels=6, Q=q).channel_W, Flocculatorita(n_channels=6, Q=q).baffle_S,Flocculatorita(n_channels=6, Q=q).total_cost]
       }
Flocculatorita(n_channels=2, Q=q).total_cost

df=pd.DataFrame(data)
print(df)
```

##Cost Comparison Code

```python
class Floc_1_min_res(Flocculatorita):
  """This class models a flocculatorita with 1 minute residence time"""
  @property
  def retention_time(self):
    return 1*u.min
  @property
  def vol(self):
    return ((self.Q*self.retention_time).to(u.L))

"""Now, Floc_1_min_res is used to estimate the cost of the floculatorita, which would handle similar flow and have the same collision potential as the current PF300 flocculator.  """
cc=Floc_1_min_res(Q=1*u.L/u.s)
print(cc.retention_time)
print(cc.total_cost)

"""Below are the calculations for the estimate of the cost of the current PF3000 flocculator"""

three_in_pvc=(32.73*u.USD)/(10*u.ft) #this is the cost of a 10' long 3" pvc pipe from [McMaster]https://www.mcmaster.com/pvc
quantity_three_in_pvc=9*2*u.m
price_three_in_pvc=quantity_three_in_pvc*three_in_pvc ##total cost of the 3" PVC pipes that will used for the floculatorita

T_three_in_pvc=	7.66*u.USD #this is the cost from [McMaster]https://www.mcmaster.com/pvc
quantity_T_three_in_pvc=10
price_T_three_in_pvc=T_three_in_pvc*quantity_T_three_in_pvc

three_in_elbow=5.22*u.USD #this is the cost from [McMaster]https://www.mcmaster.com/pvc
quantity_three_in_elbow=12
price_three_in_elbow=three_in_elbow*quantity_three_in_elbow

pvc_sheet= 56.52*u.USD#used to make light deflectors, this is the cost from [McMaster]https://www.mcmaster.com/pvc
quantity_pvc_sheet=1
price_pvc_sheet=pvc_sheet*quantity_pvc_sheet

nuts = 9.18*u.USD #the price of one pack of 25 1/4" stainless steel nuts
quantity_nuts = 1
price_nuts = nuts * quantity_nuts

reducer_3to2 = 10.28 *u.USD #price of a 3" to 2" pvc pipe reducer from McMaster
quantity_reducer_3to2= 1
price_reducer_3to2 = reducer_3to2 * quantity_reducer_3to2

reducer_2to1 = 2.43 *u.USD #price of a 3" to 2" pvc pipe reducer from McMaster
quantity_reducer_2to1= 1
price_reducer_2to1 = reducer_2to1 * quantity_reducer_3to2

PF300cost=(price_three_in_pvc+price_T_three_in_pvc+price_three_in_elbow+price_pvc_sheet+price_nuts+price_reducer_3to2 +price_reducer_2to1).to(u.USD)

comparison=cc.total_cost/PF300cost
print('The floculatorita is', comparison, 'times the cost of the current floculatorita')
```

#References
- 1: Floc Design PP
- 2: Textbook section on Floc Design https://aguaclara.github.io/Textbook/Flocculation/Floc_Design.html#equation-flocculation-floc-design-3
- 3: Floc Source Code https://github.com/AguaClara/aguaclara/blob/master/aguaclara/design/floc.py
- 4: Flocculatorita Prices. Prices are based on US markets.
    - Design diameter: Fortiline Waterworks phone call with Tom in Ohio
    - PVC Channel:https://www.eplastics.com/sheets/hdpe/black-natural?page=3
    - Obstacles:https://www.pvcfittingsonline.com/pipe/schedule-40-pvc-pipe.html

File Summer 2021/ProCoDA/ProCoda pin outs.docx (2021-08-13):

Procoda Pin Outs

RJ45 Pin | sensor3 | 24v7 / P0.7 | dio 1 / ao 1
1 | Ai 4 | | P0.1
2 | Ai 0 | | Ao 1
3 | Gnd | | Gnd
4 | -5 | | -5
5 | 5 | Gnd | 5
6 | 10 | 24v | 10
7 | -15 | | -15
8 | 15 | | 15
| sensor2 | 24v6 / P0.6 | dio 0 / ao 0
1 | Ai 5 | | P0.0
2 | Ai 1 | | Ao 0
3 | Gnd | | Gnd
4 | -5 | | -5
5 | 5 | Gnd | 5
6 | 10 | 24v | 10
7 | -15 | | -15
8 | 15 | | 15
| sensor1 | 24v5 / P0.5
1 | Ai 6
2 | Ai 2
3 | Gnd
4 | -5
5 | 5 | Gnd
6 | 10 | 24v
7 | -15
8 | 15
| sensor0 | 24v4 / P0.4
1 | Ai 7
2 | Ai 3
3 | Gnd
4 | -5
5 | 5 | Gnd
6 | 10 | 24v
7 | -15
8 | 15
| pump1 | 24v3 / P0.3
1 | P1.3
2
3 | start / stop
4 | cw / ccw
5 | Gnd | Gnd
6 | Ao 1 | 24v
7
8 | P1.2
| pump0 | 24v2 / P0.2
1 | P1.1
2
3 | start / stop
4 | cw / ccw
5 | Gnd | Gnd
6 | Ao 0 | 24v
7
8 | P1.0

11-27-13

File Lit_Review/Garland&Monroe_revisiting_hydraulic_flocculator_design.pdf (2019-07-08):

## Revisiting Hydraulic Flocculator Design for Use in Water Treatment Systems with Fluidized Floc Beds

Casey Garland,*,{ Monroe Weber-Shirk,{ and Leonard W. Lion{

School of Civil and Environmental Engineering, Cornell University, Ithaca, New York.

Received: March 30, 2016 | Accepted in revised form: July 6, 2016

Abstract
In water treatment, flocculation creates aggregated particles or flocs large enough to be removed by downstream processes of sedimentation and filtration. Fluidized beds of flocs (floc blankets) are sometimes included in upflow sedimentation processes because they can significantly improve sedimentation tank particle removal when plate or tube settlers are used. Overall performance of a sedimentation tank containing a floc blanket is influenced by the characteristics of incoming flocs from the flocculator. Floc blankets provide an additional opportunity for aggregation of colloidal particles that enables a reduction in the size of the flocculators, while improving particle removal efficiency. In this study, laminar flow flocculators varying in velocity gradient (G) and residence time (y) were tested in a laboratory scale water treatment system with a floc blanket. Results indicate that increasing G (range of 74–251 s⁻¹ ),
while decreasing residence time from 269 to 80 s, and maintaining a constant Gy (*20,000) improved particle removal. These results indicate that velocity gradients greater than existing design recommendations may be used to reduce flocculator residence times (and associated construction costs) when upflow sedimentation with a floc blanket and overlying lamellar plate or tube settlers are employed subsequent to flocculation. Further reduction of the residence time to 24 s with a G of 251 s⁻¹ resulted in a settled water turbidity of 14 nephelometric turbidity unit (NTU). When varying y at a constant G of 72 s⁻¹
, an apparent minimum in settled effluent turbidity at 0.15 NTU was observed at the middle residence time tested (y = 211 s), suggesting that long hydraulic flocculator residence times may be suboptimal.

Keywords: coagulant; flocculation; fluid mechanics; sedimentation

Introduction

Designing an efficient water treatment process train that includes flocculator, floc blanket, plate settlers, and sand filtration is hindered by a limited understanding of how these sequential processes interact. Bache and Gregory (2010) have noted that smaller flocs are more desirable for floc blanket clarifiers and it follows that it might be beneficial to design upstream flocculators to produce smaller flocs. Small flocs can be produced by reducing flocculator hydraulic residence time (y) so that flocs do not have time to grow very large, or through increasing fluid shear by increasing the velocity gradient (G) so that floc size is limited. Flocs formed under conditions of higher shear are smaller and thus more dense (Burban et al., 1989; Carissimi et al., 2007). However, excessively high shear produces very small flocs that may settle more slowly than the capture velocity of a sedimentation system resulting in an unacceptable performance (Garland et al., 2016). Thus, it is unclear how varying flocculator residence time and velocity gradient might beneficially change the floc blanket suspended solids concentration and the system performance as measured by settled effluent (or residual) turbidity.
Flocculator design is traditionally based on the product of G and y, known as the Camp number (Gy). Although G may only be appropriate for laminar flow conditions (Cleasby, 1984), it is conventionally used for design of turbulent flocculators. The flocculators used in this study were laminar flow and thus G is an appropriate parameter for the laboratory scale flocculator. Suggested values for Gy for turbulent mechanically mixed flocculators range from 20,000–75,000, with G ranging from 20 to 75 s⁻¹ (AWWA/ASCE, 2012; Gregory, 1979). It was not assumed that these parameters were directly applicable to a laminar flow tube flocculator, especially given the nonuniformity of the energy dissipation rate (EDR) in mechanically mixed flocculators (Bouyer et al., 2005).
Recommended minimum residence time for flocculators varies from 10 min (AWWA/ASCE, 2012) to 30 min (Great Lakes—Upper Mississippi River Board of State and Provincial Public Health and Environmental Managers, 2012). It is likely that guidelines for flocculator G and y were developed based, in part, on the experience where a low Peclet number mechanically mixed flocculator was followed

*Corresponding author: Casey Garland, School of Civil and Environmental Engineering, Cornell University, 220 Hollister Hall, Ithaca, NY 14853. Phone: 607-255-3438; Fax: 607-255-9004; E-mail: cag266@cornell.edu {
Member of AEESP.

ENVIRONMENTAL ENGINEERING SCIENCE Volume 34, Number 2, 2017
ª Mary Ann Liebert, Inc.
DOI: 10.1089/ees.2016.0174

122

Downloaded by Cornell University package NERL from www.liebertpub.com at 07/08/19. For personal use only.

by a conventional horizontal flow sedimentation tank. The applicability of these guidelines is uncertain in cases where a high Peclet number hydraulic flocculator (Weber-Shirk and Lion, 2010) is followed by an upflow sedimentation tank with a floc blanket and lamellar sedimentation.
Smaller flocculators use fewer materials and cover a smaller area, reducing the overall cost of the plant. Given the conventional design criterion for Gy, increasing G would mean a subsequent decrease in y to maintain constant Gy. In the laminar regime, G scales with the square root of the average EDR,

e. When using turbulent hydraulic flocculators, increasing -e can
be achieved by decreasing baffle spacing and y can be decreased reducing the flocculator volume. It is not clear whether this trade-off is capable of producing flocs that will build a high performance floc blanket or be removed by downstream processes. Smaller flocs (due to low coagulant doses) have been shown to increase blanket suspended solids concentration (Bache, 2010), likely due to the inherent fractal nature of flocs that makes small flocs denser. Hurst et al.(2010) found that floc blanket suspended solids concentration dictated performance of the system, with higher concentrations improving performance. Given that the mechanism for solids removal in the floc blanket has been attributed to flocculation and/or filtration, it is possible that the capacity of a flocculator could be reduced in a process train with a floc blanket because the floc blanket will provide an opportunity for further flocculation.
In this research, experiments were conducted to determine the impact of flocculator design on a laboratory-scale water treatment plant with a flocculator, a floc blanket, and tube settlers. Seven alternative flocculator designs were compared: three flocculators with the same Gy and different G and y values; three flocculators with the same G, but increasing y; and one flocculator with a high G and low y.

Experimental Protocol

The laboratory-scale experimental apparatus was the same as described by Hurst, et al. (2014) with the exception that a floc weir was used to limit floc blanket height, and almost all influent fluid was removed from the reactor by passage through tube settlers. A schematic of the apparatus is provided in Fig. 1. The height of the floc weir was 86 cm from the bottom of the jet reverser. Velocity of water through the jet reverser was 1.6 m/s. Angle of the bottom slope is 45-and
diameter of the round inlet jet tube was 4.6 mm. Aerated tap water (average pH 7.36, total alkalinity 131 mg/L as CaCO3, total hardness 150 mg/L as CaCO3, dissolved organic carbon 1.83 mg/L) (City of Ithaca, 2014) was mixed with an 8 g/L stock kaolinite clay suspension (R.T. Vanderbilt Co., Inc. Norwalk, CT.) to form a 100 nephelometric turbidity unit (NTU) synthetic raw feed water. To maintain a steady influent suspended solids concentration, an inline turbidity meter monitored the turbidity (HF Scientific Microtol Inline Turbidity Meter, Range: 0–1,000 NTU) and Proportional Integral Derivative control implemented with Process Control and Data Acquisition (ProCoDA, 2015) software was used to meter the clay stock. Polyaluminum chloride (PACl; PCH-180 Holland Co., Adams, MA) was mixed to create a stock 567 mg/L as Al and added to the influent stream using a peristaltic pump (Cole Parmer MasterFlex L/S, 1.6–100 RPM Peristaltic Pump). The flow rate of the pump was adjusted to obtain a PACl dose of 1.25 mg/L as Al. Effluent turbidity was measured with an inline turbidity meter (HF Scientific Microtol Inline Turbidity Meter, Range: 0–1,000 NTU) after the tube settlers and recorded every 5 s for the duration of each experiment. Floc blanket concentration measurements were made through digital image analysis of light absorbance as described by Hurst et al. (2014). Images were acquired at 60-second intervals with a Basler (Basler, Ahrensburg,
Germany) | color | SCA640-70FC | IEEE-1394B | camera
(658 · 490 pixels) using an 8 mm lens. Image field of view was 98.9 · 73.5 cm. Images for the floc blanket solids concentration region (see region indicated in Fig. 1) were processed postexperiment to obtain suspended solids concentrations using LabVIEW software.
Performance of the system comprised of a flocculator, sedimentation tank, and tube settlers with no floc blanket was determined using the effluent turbidity after one full hydraulic

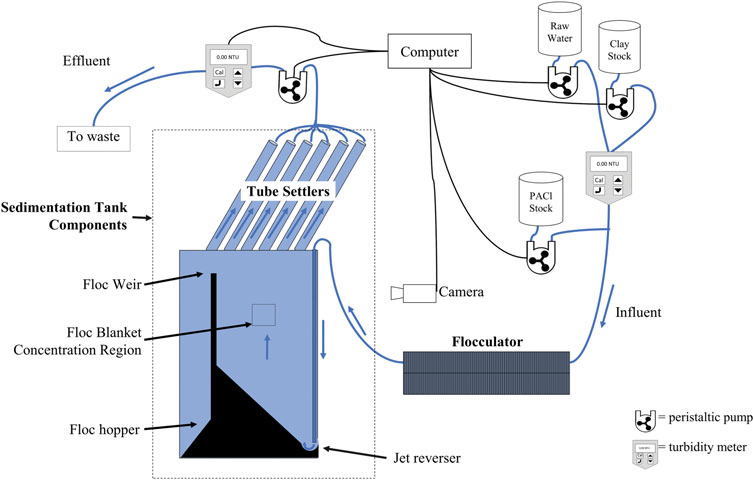
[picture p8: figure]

FIG. 1. Design schematic
of experimental apparatus. Influent to the sedimentation tank from the flocculator entered through a tube directed downward into the jet
reverser. The flow was
redirected upward by the
semicircular jet reverser. The region of interest utilized for image analysis of floc blanket suspended solids concentrations is indicated with dashed lines. Ten percent of the total flow was sent to waste because it was insufficient to support an additional tube settler. Items in the shaded region indicate the postflocculator processes (i.e., the floc blanket plus tube settlers) considered in the sedimentation tank. PACl, polyaluminum chloride.
FLOCCULATOR DESIGN AND FLUIDIZED FLOC BED SYSTEMS | 123

Downloaded by Cornell University package NERL from www.liebertpub.com at 07/08/19. For personal use only.

residence time of the flocculator, sedimentation tank, and tube settlers. The beginning of steady state was defined as when the floc blanket height reached the top of the floc weir and the floc blanket concentration was constant within –2.5% of the mean concentration over the residence time of fluid in the floc blanket. After steady state was reached, data were averaged for one hydraulic residence time of the sedimentation tank (8.3 min) to obtain steady state floc blanket concentration and effluent turbidity.
In a typical water treatment process train, a filter would follow sedimentation and, assuming 90% particle removal through filtration, the highest turbidity that could be sent to the filter and still produce a final effluent turbidity at or below EPA standards would be 3 NTU. Thus, settled effluent turbidity ‡3 NTU was adopted as criterion for failure of the upstream flocculator/floc blanket/tube settler system. The time required to form each floc blanket was also noted and Gy combinations that resulted in long formation times are considered undesirable.
Six tube settlers with a capture velocity (also referred to as a critical velocity) of 0.1 mm/s were utilized for this experiment. Tubes were 1 in. PVC with a flow rate of 0.9 mL/s (per tube) set at 60-from the horizontal. The flocculator EDR was altered by changing the diameter of the flocculator tubing and the flocculator hydraulic residence time was adjusted by changing the length of tubing. Energy dissipated in the flocculator was determined by first calculating the major head loss due to laminar flow through the same length of straight tube using the Hagen–Poiseuille equation,

hf ¼ 128v
gp

LQ

DTube

4 | (1)
where m is the kinematic viscosity of water—1.0 mm² | /s at
20-C, L is the length of the flocculator, Q is the flow rate, and DTube is the inner diameter of the tube.
Total energy losses accrued (including losses caused by the curvature of the helically coiled flocculator, hCoil) were determined according to Berger et al. (1983):

hCoil ¼ hf 1 þ 0:033 log Re ffiffiffiffiffiffiffiffiffiffiffi DTube

DCoil | | r | 4 ( | ) (2)

where hf is the major head loss from Equation (1), DTube is the inner diameter of the flocculator tube, DCoil is the diameter of the coil, and Re is the Reynold’s number (Re ¼ VDTube
v , where
q is the density of water, V is the average velocity of the fluid) of the flow, which ranged from 814 to 1,222. The average EDR, -eFlocculator, was determined as follows:

eFlocculator ¼ hCoilg
h | (3)

where y is the hydraulic residence time of the flocculator. Average velocity gradient, G, was calculated as follows:

G ¼

ffiffiffiffiffiffiffiffiffiffiffiffiffiffiffiffiffiffi

eFlocculator
v

r
(4)

Characteristics of the experimental flocculators are summarized in Table 1. Replicate experiments were performed for each Gy combination.

Major head loss was measured for flocculator 2 (G = 126 s⁻¹ ,
y = 159 s) to verify calculations. Theoretical head loss was calculated to be 27.8 cm using Equations (1) and (2) and actual head loss was measured with a pressure sensor to be 26.2 cm. Due to coagulant and clay to the walls, head loss increased with run time. Approximately 0.7% of influent was lost to flocculator walls and head loss increased at a mean rate of 10.4 mm/hr during experiments. Consequently, in all flocculators, final G was higher than initial flocculator G.
EDR through the floc blanket is a function of the solids concentration within the floc blanket and was calculated as follows (Hurst et al., 2010):

eFB ¼ gVUp
F

0:687Cs

qWater

(5)

where VUp is the upflow velocity of the sedimentation tank, CS is the suspended solids concentration of the floc blanket, F is the porosity of the floc blanket (85% based on settling tests), and qWater is the density of water (998 kg/m³ at 20-C).
A G for the floc blanket, GFB, was determined by combining Equations (4) and (5) such that the EDR of the flocculator, eFlocculator, is substituted by the EDR of the floc blanket, eFB,

GFB ¼

ffiffiffiffiffiffi

eFB
v

r
(6)

Results

An example of all data collected for an experiment is presented in Fig. 2. A summary of steady-state floc blanket concentration and effluent turbidities can be found in Table 2.

Maintaining a constant Gh and varying G

The velocity gradient, G, of the flocculator was changed, while maintaining a constant Gy of *20,000. Flocculators with G values of 74, 126, and 251 s⁻¹ (EDR of 5.5, 16, and 63 mW/kg, respectively) were utilized with simulated raw water of 100 NTU and PACl dose of 1.25 mg/L as Al. Floc blanket suspended solids concentrations increased slightly with the higher flocculator G, while tube settler turbidity decreased with a higher flocculator G (Fig. 3). The effluent turbidity of the two flocculators with the lower G values was on the borderline of failure.
Effluent turbidity without a floc blanket was not significantly different across experiments (Fig. 4). Based on the difference in performance with and without a floc blanket, the highest G experiment demonstrated the largest improvement and the best performance when the floc blanket had formed. The lower and intermediate G experiments also improved with the presence of a floc blanket.

Changing flocculator residence time

Experiments were conducted holding flocculator G constant (72 s⁻¹ and close to the lowest G value tested at constant Gy) and changing y (24, 211 and 1,425 s). As flocculator residence time increased, the floc blanket suspended solids concentration decreased (Fig. 5). Floc blanket suspended solids concentration for the longest residence time averaged 2,100 mg/L and increased to 4,500 mg/L for the shortest

124 | GARLAND ET AL.

Downloaded by Cornell University package NERL from www.liebertpub.com at 07/08/19. For personal use only.

residence time. Effluent turbidity reached minimum values at the intermediate 211 s residence time.
Effluent turbidity without a floc blanket was highest for the lowest residence time flocculator and very similar at higher residence times (Fig. 6). As the residence time of the flocculator increased, the contribution of the floc blanket to solids removal tended to decrease.
Given that the lowest residence time flocculator (G = 72 s⁻¹ )
had a higher effluent turbidity than other experiments with similar G (Fig. 5) and higher flocculator G values produced lower effluent turbidity (Fig. 3), it was expected that increasing flocculator G, while maintaining the residence time, might improve system performance. Figure 7 shows the results of the high G (251 s⁻¹
), low y (24 s) experiment alongside the low G (72 s⁻¹
), low y experiment in Fig. 4, which produced high effluent turbidity. Both floc blanket concentration and effluent turbidity increased with the higher G flocculator. Effluent turbidity averaged 14.3 NTU for both experiments, indicating that the system was in failure with this flocculator.

Discussion

Flocculators and floc blanket concentrations

Increasing the velocity gradient of the flocculator would be expected to produce smaller flocs as floc size scales inversely with shear (Parker et al., 1972; Spicer and Pratsinis, 1996; Jarvis et al., 2005). Generally, small flocs produce higher floc blanket concentrations (Su et al., 2004; Bache, 2010; Hurst et al., 2010). Higher floc blanket suspended solids concentrations were observed with higher G flocculators and low residence time flocculators supporting expectations that smaller flocs were produced from these conditions. In the case of the short residence time flocculator, floc size was likely set by insufficient opportunity for particle collisions. A floc resulting from a collision between a small and large floc (particle to cluster aggregation) will have a higher mass fractal dimension with a higher density than the original large floc (Gregory, 1997). In addition, flocs formed in high G conditions were observed by Jung et al. (1996) to be more

Table 1. Characteristics of Each Flocculator for Each Set of Experiments

| DTube (mm) | h (s) | G (s⁻¹
) | Gh | Re | De
| | | | | | | Calculated
| | | | | | | head loss (cm) | Mean floc blanket formation time (h)a
1 | 6.5 | 80 | 251 | 20,080 | 1222 | 264 | 56.0 | 12.9
2 | 7.9 | 159 | 126 | 20,034 | 976 | 243 | 27.8 | 25.5
3 | 9.5 | 269 | 74 | 19,906 | 815 | 262 | 15.2 | 16.1
4 | 9.5 | 24 | 72 | 1,728 | 815 | 213 | 1.2 | 18.6
5 | 9.5 | 211 | 72 | 15,192 | 815 | 213 | 11.0 | 13.1
6 | 9.5 | 1,425 | 72 | 102,600 | 815 | 213 | 74.0 | 12.1
7 | 6.5 | 24 | 251 | 6,024 | 1222 | 325 | 15.4 | 22.1

a
Values are averages of two experiments.

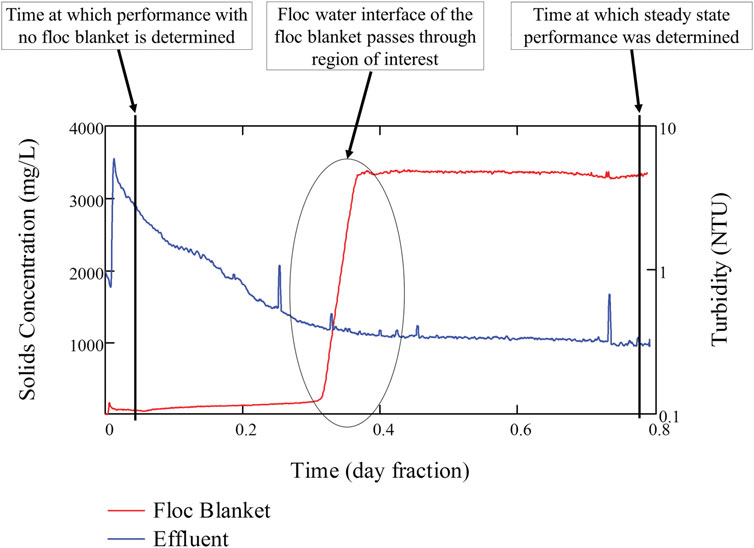
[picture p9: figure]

FIG. 2. Example of floc
blanket suspended solids
concentration and effluent turbidity over time through an experiment (G = 72 s⁻¹
,
y = 211 s). Effluent turbidity is plotted on the secondary y-axis. The total length of time used for averaging both steady-state and no floc
blanket performance is 150 s.

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

compact and had a higher fractal dimension. We hypothesize that the collisions between small flocs coming from the flocculator and large fully grown flocs in the floc blanket produce flocs with a higher mass fractal dimension, increasing the floc density and thus the solids concentration. As flocs enter the floc blanket where shear is much lower than that in the flocculator (GFB = 4.4–6.4 s⁻¹ for floc blankets produced in these experiments calculated by Equation (6); flocculator G’s of 72–251 s⁻¹
), they will grow in size until the shear in the floc blanket prevents further growth. As small flocs enter the floc blanket from the flocculator, they collide with large floc blanket flocs resulting in a floc with increased density and fractal dimension. As a result, flocculators that produce a large number of small flocs (high G or low residence time flocculators) are expected to produce higher concentration floc blankets.
Li and Logan (1997) looked at collision efficiencies between fractal aggregates and colloids and concluded that colloid removal efficiencies were related to the porosity of the fractal. Larger, more porous flocs were seen to be more permeable allowing water to flow through them achieving rectilinear fluid motion and capture of small colloids. As the large porous flocs accumulated colloids and floc porosity decreased, water would tend to travel around the fractal aggregate (curvilinear motion) and decrease colloid capture. This observation also suggests that floc blanket flocs may have a limited capacity for collisions with small particles and finite capacity for particle to cluster aggregation. In the case of a floc blanket, dense flocs resulting from particle to cluster aggregation would remain fluidized and increase the suspended solids concentration as well as coupled EDR (and thus number of collisions of small like-sized particles) in the floc blanket. Thus, small particle removal may occur through a combination of particle-to-cluster aggregation (creating dense flocs and a higher floc blanket suspended solids concentration) and increased like-sized small floc collisions promoted by the ensuing higher EDR in the floc blanket. Tambo and Hozumi (1979) modeled contact flocculation under the assumption that only collisions between grown flocs and small flocs were significant. The basis for this assumption was directed at modeling the number of small flocs removed in the fluidized bed; however, the assumption is as relevant to understanding the increase in floc blanket suspended solids concentration as it is to what collisions are significant.
The flocculator with lowest G (and longest residence time) created the least concentrated floc blanket (Fig. 5). Flocs from this flocculator would have been the largest due to the low G, and the number of small flocs would have been minimized due to the long residence time. As a result, it is expected that there would have been very few small flocs to collide with floc blanket flocs to increase the overall suspended solids concentration. This reasoning is consistent with the low floc blanket solids concentrations observed in the low G, long y experiment.

Potential for collisions in the floc blanket

The mechanism by which the floc blanket improves system performance in terms of settled water turbidity is thought to be removal of small flocs through flocculation (collisions between small flocs) and/or filtration (collisions between small and grown flocs). Higher floc blanket suspended solids

Table 2. Experiment Results for Each Flocculator

| h (s) | G (s⁻¹
) | Gh
| | | | Steady-state
| | | | floc blanket
| | | | concentration (mg/L)a | Steady-state
| | | | | effluent
| | | | | turbidity (NTU)a
1 | 80 | 251 | 20,080 | 4,300 | 0.15
2 | 159 | 126 | 20,034 | 4,100 | 1.9
3 | 269 | 74 | 19,906 | 3,700 | 2.2
4 | 24 | 72 | 1,728 | 4,500 | 0.38
5 | 211 | 72 | 15,192 | 3,700 | 0.15
6 | 1,425 | 72 | 102,600 | 2,100 | 0.8
7 | 24 | 251 | 6,024 | 5,500 | 14.1

a
Values are averages of two experiments.
NTU, nephelometric turbidity unit.

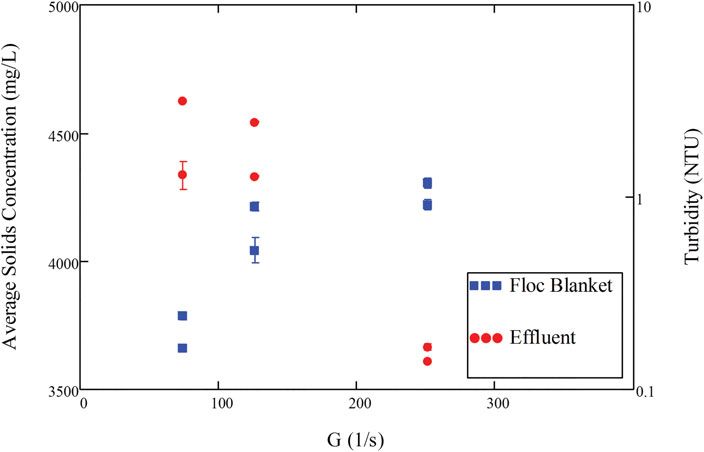
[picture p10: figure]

FIG. 3. Steady-state average suspended solids concentrations in the floc blanket and effluent turbidity at flocculator G values 74, 126, and 251 s⁻¹ and constant Gy&20,000. Effluent turbidity points correspond to the secondary y-axis. Error bars indicate the standard deviation of each experiment; however, they are about the same size of the point symbol in many cases. Replicates are shown for each experiment.

126 | GARLAND ET AL.

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

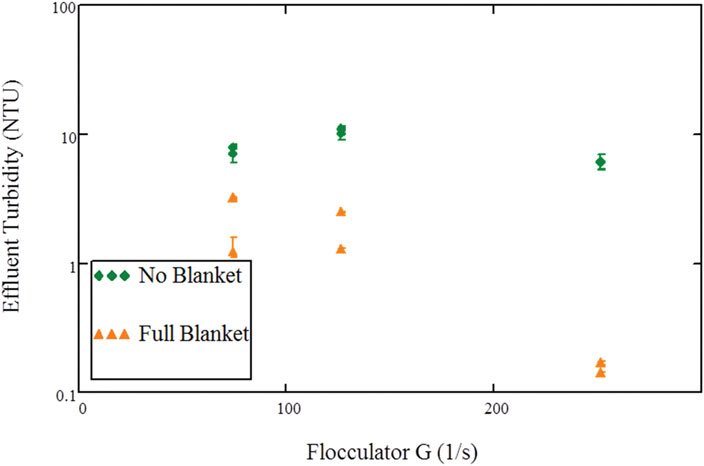
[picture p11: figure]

concentrations would be expected to have better removal because the distance a floc must travel before colliding with another floc is small compared to a lower concentration floc blanket. Higher shear in the floc blanket at high suspended solids concentration would also increase the number of small floc collisions occurring in the floc blanket. The overall performance of a floc blanket is controlled by the removal of small flocs that would otherwise escape the tube settlers. Growing flocs to the largest possible size is not the operational goal; instead it is to ensure the smallest flocs grow to be large enough to be captured by the tube settlers. Thus, floc blanket design should encourage collisions with the smallest flocs to reduce effluent turbidity. This can be achieved with higher floc blanket suspended solids concentrations that create higher shear and hence more collisions between small flocs and between small and grown floc blanket flocs.
In experiments where G was varied, but Gy remained the same (Figs. 3 and 4), the two highest G flocculators produced blankets with very similar suspended solids concentrations, but notably different effluent turbidities (0.15 NTU at G = 251 s⁻¹ and 1.9 NTU at G = 126 s⁻¹
). Given the high suspended solids concentration of the floc blanket and smaller size of flocs exiting from the highest G flocculator, it is possible that this Gy combination represents an optimal condition where the floc blanket suspended solids concentration is high, increasing collisions, and the flocs from the flocculator are small so that the smallest flocs, which would have otherwise escaped the tube settlers, grow to a size that can be captured. When the same flocculator G with lower residence time was used, effluent turbidity was very high (14.3 NTU) even though the floc blanket suspended solids concentration was high (Fig. 7). Poor performance in this case was likely the result of too many small flocs with sedimentation velocities less than the capture velocity of the tube settlers. Although some of these flocs were undoubtedly captured in the floc blanket, too many of them escaped and were not able to be captured by the tube settlers. The lowest suspended solids concentration floc blanket was created by the low G, long y flocculator (Fig. 5). Interestingly,

FIG. 4. System performance with and without a floc blanket for experiments with increasing G and constant Gy. Error bars are shown; however, they are about the same size of the point symbol in many cases. Replicates are shown for each experiment.

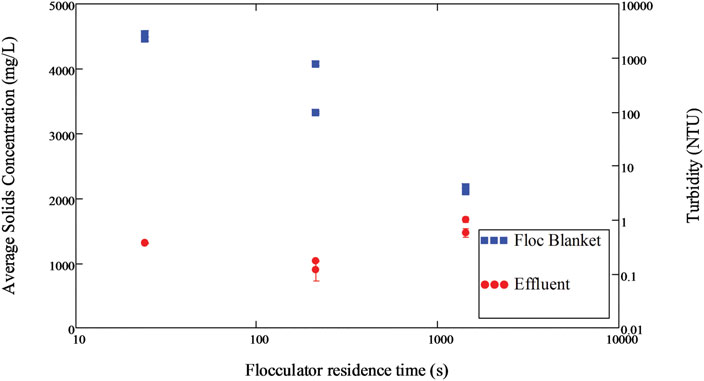
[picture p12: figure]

FIG. 5. Steady-state average system concentrations at G = 72 s⁻¹ and varying flocculator residence time. Error bars are shown; however, they are about the same size of the point symbol in many cases. Replicates are shown for each experiment.

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

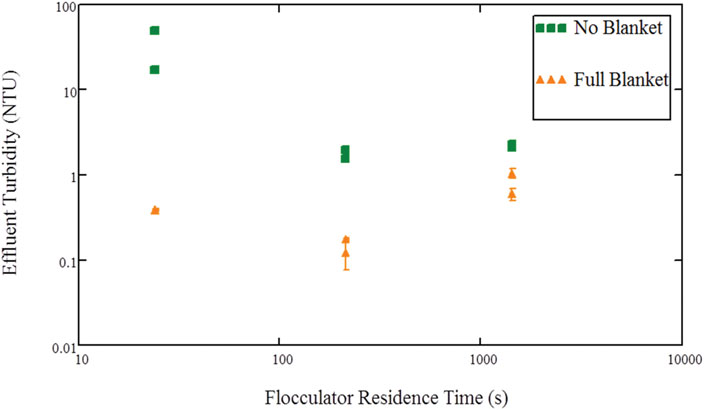
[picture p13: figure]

the effluent turbidity of the system without a floc blanket in this case (Fig. 6) was very similar to those for the intermediate y flocculators suggesting that flocs leaving both flocculators were similar in overall size and had settling velocities higher than the capture velocity of the tube settlers. In Fig. 5, it is apparent that there was a minimum steady-state effluent turbidity at the intermediate residence time. Although the research presented in this study does not reveal the optimal residence time producing the lowest effluent turbidity, it is important to note that additional y was not helpful, but in fact reduced system performance with a floc blanket.

Practical considerations

In practice, it takes time for a floc blanket to form and the high effluent turbidity during this interval is an important consideration. From experiments with constant Gy, the low and high G flocculators had lower formation times relative to the intermediate G flocculator (Table 1), but all produced a higher effluent turbidity without a floc blanket (Fig. 4). From the experiments with varying flocculator y, the intermediate and longest y had reasonable effluent turbidity without a floc blanket (Fig. 6) and formation times relative to the flocculator with the lowest y (Table 1). For all cases tested, the formation time was generally longer in flocculators that produced poor effluent turbidity without a blanket during startup or during steady-state operation. System performance would decrease in all cases if the tube settler capture velocity was increased and must be accounted for in system designs.
The results presented in this article indicate that flocculator design can influence floc blanket suspended solids concentration and effluent turbidity. Some decrease in flocculator hydraulic residence time (and coupled construction costs) may be accomplished through the use of higher G. However, direct use of Gy based on the results presented above where the experimental flow was laminar should not be applied for system design for turbulent flocculators or flocculators with high temporal and spatial variability in EDR. Hydraulic flocculation research under conditions of turbulence is needed to better define the tradeoff between hydraulic residence time and the EDR.

FIG. 6. System concentrations with and without a floc blanket for experiments with increasing y and constant G (72 s⁻¹
). Error bars are
shown; however, they are about the same size of the point symbol in many cases. Replicates are shown for each experiment.

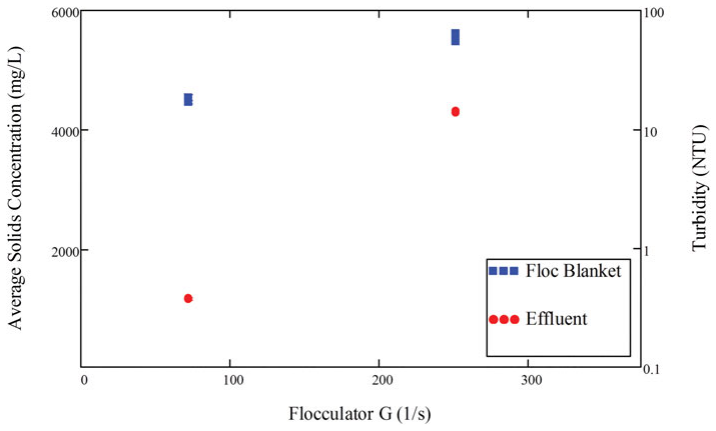
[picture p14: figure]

FIG. 7. Steady-state average system concentrations at low (72 s⁻¹

) and high G (251 s⁻¹
) and
constant flocculator residence time. Error bars are shown; however, they are about the same size of the point symbol in many cases. Replicates are shown for each experiment.
128 | GARLAND ET AL.

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

Summaries

The research presented in this article shows that the current guidelines do not produce optimal results when a floc blanket is used. At constant Gy, the lowest velocity gradient tested (and the highest suggested by design guidelines) performed the worst (Fig. 3) and the lowest settled effluent turbidity was observed at the highest velocity gradient tested. In experiments with constant G and varying y, there was an apparent minimum in effluent turbidity (Fig. 5) where an increase in y did not improve turbidity removal. Over the 62-fold reduction in experimental flocculator residence time tested (from 1,425 to 24 s), the effluent turbidity increased by about 0.43 NTU suggesting that smaller flocculator could be used in series with a floc blanket.
Flocculators used in this article created a range of floc blanket concentrations (2,100–5,500 mg/L) when a constant PACl dose was used. Previous research has strongly suggested that higher floc blanket concentrations are related to better floc blanket performance (Gregory et al., 1996; Hurst et al., 2010); thus it might be possible to improve performance of a water treatment plant by designing a flocculator that will produce a high concentration floc blanket. Experimental results suggest that, within reasonable limits, hydraulic flocculators with residence times that are shorter than recommended limits and velocity gradients above recommended limits might be a means to improve performance assuming a floc blanket and lamellar sedimentation are employed. Design of a water treatment plant has never been optimized for cost and/or performance, and these results suggest that flocculators could be smaller, and likely less expensive, in optimized designs. Smaller flocculators use fewer materials and require less area to build. These results may be more directly applicable to hydraulic flocculators designed to have a more uniform EDR as opposed to mechanical flocculators with a large difference between maximum and average EDR. Further research is needed to understand how flocculator design, suspension properties, and coagulant dose control floc size distributions and subsequent particle capture by floc blankets and lamellar sedimentation.

Acknowledgment

This research was supported, in part, by National Science Foundation award ID 1437961.

Author Disclosure Statement

No competing financial interests exist.

References

American Water Works Association and American Society of Civil Engineers (AWWA/ASCE). (2012). Water Treatment Plant Design, 5th edition. New York: McGraw-Hill. Available at: http://accessengineeringlibrary.com/browse/water-treatmentplant-design-fifth-edition (accessed March 3, 2016).
Bache, D.H. (2010). Model of dynamic and macroscopic features of a floc blanket. J. Water Supply Res. Technol. AQUA 59, 53. Bache, D.H., and Gregory, R. (2010). Flocs and separation processes in drinking water treatment: A review. J. Water Supply Res. Technol. AQUA 59, 16.

Berger, S.A., Talbot, L., and Yao, L.-S. (1983). Flow in curved pipes. Annu. Rev. Fluid Mech. 15, 461.
Bouyer, D., Escudie´, R., and Line´, A. (2005). experimental analysis of hydrodynamics in a Jar-test. Process Saf. Environ. Prot. 83, 22.
Burban, P.-Y., Lick, W., and Lick, J. (1989). The flocculation of finegrained sediments in estuarine waters. J. Geophys. Res. 94, 8323. Carissimi, E., Miller, J.D., and Rubio, J. (2007). Characterization of the high kinetic energy dissipation of the flocs generator reactor (FGR). Int. J. Miner. Process. 85, 41. Cleasby, J.L. (1984). Is velocity gradient a valid turbulent flocculation parameter? J. Environ. Eng. 110, 875.
City of Ithaca. (2014). Drinking Water Quality Report. Available at: https://energyandsustainability.fs.cornell.edu/file/AWQR_2014.pdf (accessed August 17, 2016).
Garland, C., Weber-Shirk, M., and Lion, L.W. (2016). Influence of variable inlet jet velocity on failure modes of a floc blanket in a water treatment process train. Environ. Eng. Sci. 33, 79. Great Lakes—Upper Mississippi River Board of State and Provincial Public Health and Environmental Managers (GLUMRB). (2012). Recommended Standards for Water Works. Albany, NY. Available at: http://10statesstandards.com/waterrev2012.pdf Gregory, J. (1997). The density of particle aggregates. Water Sci. Technol. 36, 1.
Gregory, R. (1979). Floc Blanket Clarification. TR III. Swindon, UK: Water Research Centre.
Gregory, R., Head, R.J.M., and Graham, N.J.D. (1996). The relevance of blanket solids concentration in understanding the performance of floc blanket clarifiers in water treatment. In H.H. Hahn, E. Hoffman, and H. Odegaard, Eds., Chemical Water and Wastewater Treatment IV. Berlin, Germany: Springer, p. 17. Available at: http://dx.doi.org/10.1007/978-3-642-61196-4_2 (accessed February 23, 2016).
Hurst, M., Weber-Shirk, M., and Lion, L.W. (2010). Parameters affecting steady-state floc blanket performance. J. Water Supply Res. Technol. AQUA 59, 312.
Hurst, M., Weber-Shirk, M., and Lion, L.W. (2014). Apparatus for observation and analysis of floc blanket formation and performance. J. Environ. Eng. 140, 11.
Jarvis, P., Jefferson, B., Gregory, J., and Parsons, S.A. (2005). A review of floc strength and breakage. Water Res. 39, 3121. Jung, S.J., Amal, R., and Raper, J.A. (1996). Monitoring effects of shearing on floc structure using small-angle light scattering. Powder Technol. 88, 51.
Li, X.Y., and Logan, B.E. (1997). Collision frequencies between fractal aggregates acid small particles in a turbulently sheared fluid. Environ. Sci. Technol. 31, 1237.
Parker, D., Kaufman, W., and Jenkins, D. (1972). Floc breakup in turbulent flocculation processes. J. Sanit. Eng. Div. Proc. Am. Soc. Civ. Eng. 98, 79.
Process Control and Data Acquisition (ProCoDA). (2015). An automated method for testing process parameters. Available at: https://confluence.cornell.edu/display/AGUACLARA/ProCoDA (accessed May 25, 2016).
Spicer, P.T., and Pratsinis, S.E. (1996). Shear-induced flocculation: The evolution of floc structure and the shape of the size distribution at steady state. Water Res. 30, 1049.
Su, S.T., Wu, R.M., and Lee, D.J. (2004). Blanket dynamics in upflow suspended bed. Water Res. 38, 89.
Tambo, N., and Hozumi, H. (1979). Physical aspect of flocculation process—II. contact flocculation. Water Res. 13, 441. Weber-Shirk, M., and Lion, L.W. (2010). Flocculation model and collision potential for reactors with flows characterized by high Peclet numbers. Water Res. 44, 5180.

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

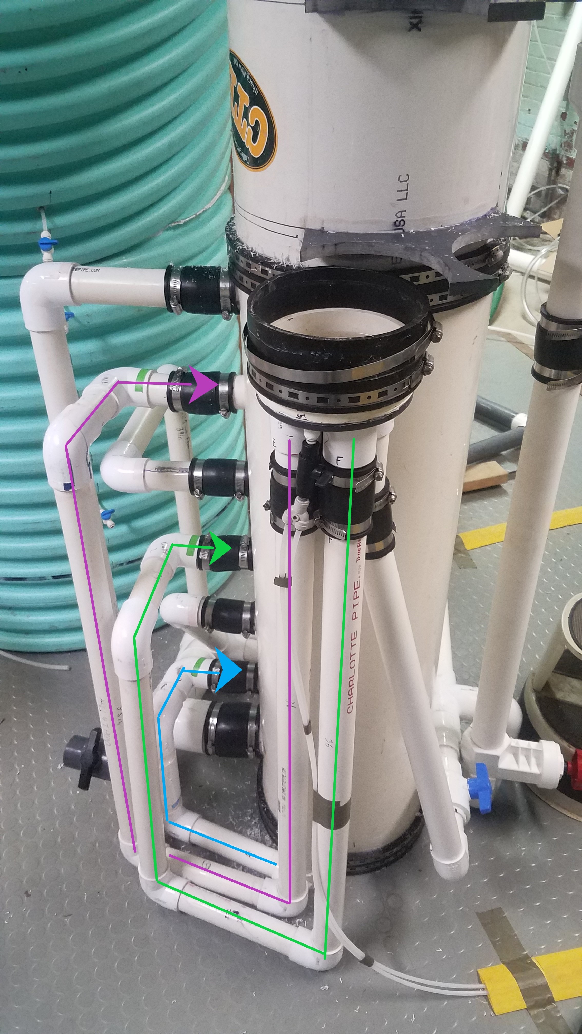
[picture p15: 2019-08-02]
Spring 2020/Images/Report/Exit_tank.jpg

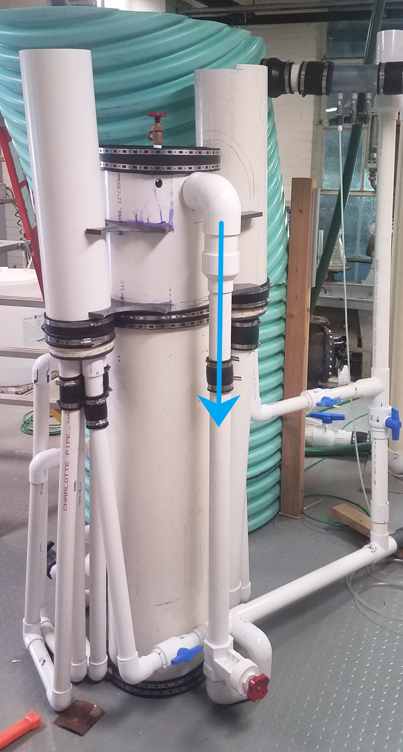
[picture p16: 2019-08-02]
Spring 2020/Images/Report/Filter_backwash.jpg

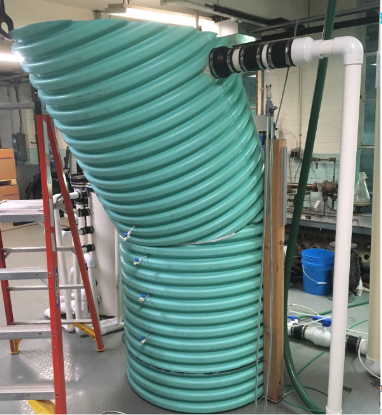
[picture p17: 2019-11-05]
Spring 2020/Images/Sedimentation tank.PNG

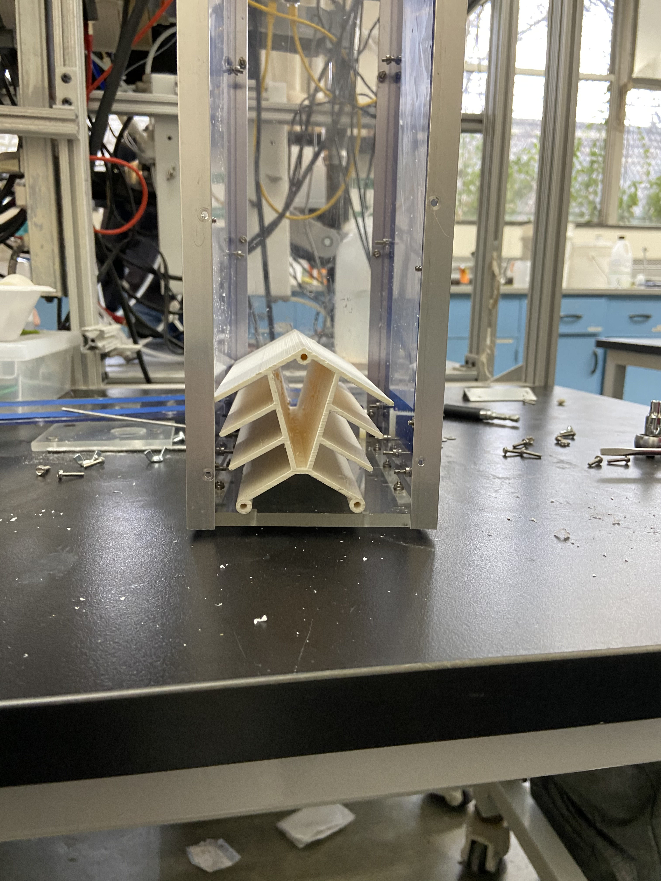
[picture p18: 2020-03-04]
Spring 2020/Images/p.JPG

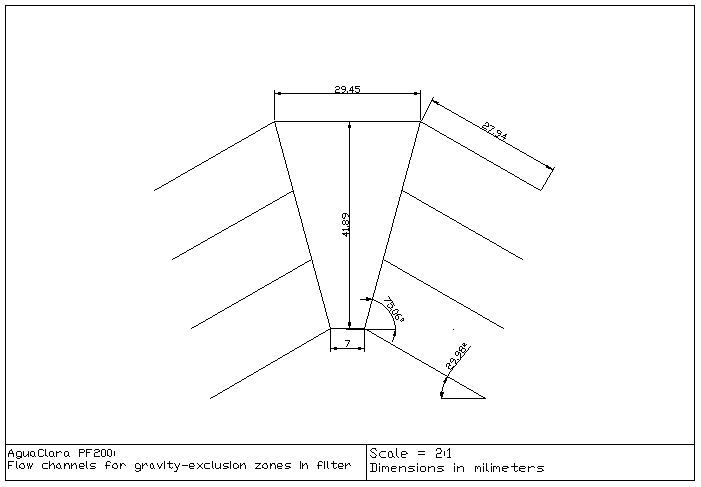
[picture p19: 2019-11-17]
Spring 2020/Images/Cross section 2.PNG

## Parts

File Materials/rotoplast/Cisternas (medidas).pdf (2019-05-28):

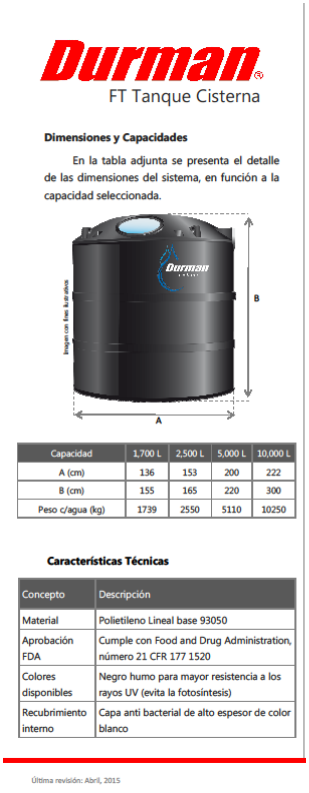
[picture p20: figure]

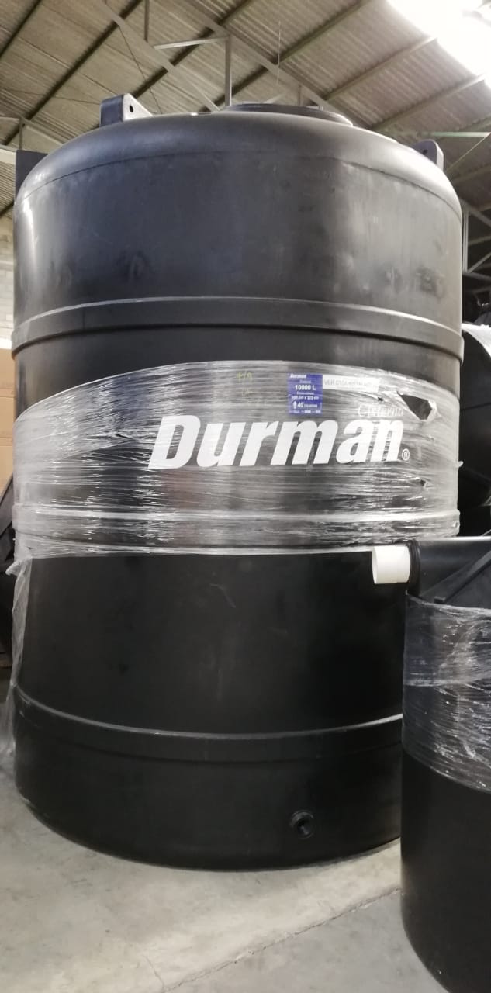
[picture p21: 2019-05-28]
Materials/rotoplast/Nueva cisterna 10k.jpg

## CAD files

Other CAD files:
designs/autocad_honduras_1.dwg

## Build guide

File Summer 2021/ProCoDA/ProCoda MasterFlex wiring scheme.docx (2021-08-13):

DB-15

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
PIN6

PIN4

PIN3

PIN5

PIN6

PIN4

PIN3

PIN5

DB-9

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
PIN6

PIN3

PIN5

Analog pump cables (DB9) Model No. 7521-50

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
ProCoda MasterFlex RJ45 wiring scheme

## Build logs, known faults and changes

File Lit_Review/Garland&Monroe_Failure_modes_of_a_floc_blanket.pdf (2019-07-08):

ORIGINAL ARTICLES

## Influence of Variable Inlet Jet Velocity on Failure Modes of a Floc Blanket in a Water Treatment Process Train

Casey Garland,* Monroe Weber-Shirk,{ and Leonard W. Lion{

School of Civil and Environmental Engineering, Cornell University, Hollister Hall, Ithaca, New York.

Received: August 21, 2015 | Accepted in revised form: October 23, 2015

Abstract
Improving designs of facilities that employ floc blankets in a water treatment process train to ensure stable performance is desirable, as is an understanding of suitable operating conditions to maintain a functional floc blanket in the system. By considering sequential processes when choosing design parameters, the whole system can be optimized to produce high quality effluent at low cost. A lab scale water treatment system with flocculator, floc blanket, and lamellar sedimentation was used to evaluate the effect of energy dissipation rates (EDR) in the inlet jet to the floc blanket on performance of the system as a whole. Results show that presence of a floc blanket provided an additional factor of 8 decrease in settled water suspended solids concentration at an upflow velocity 1.2 mm/s. Inlet jet EDR did not impact system performance until *300 mW/kg after which settled water turbidity increased. At the lower end of inlet jet EDR tested, the jet was unable to resuspend settled flocs. Given that plant performance was acceptable at higher inlet jet EDR, smaller inlet jets with a higher velocity could be used to ensure resuspension of flocs for continuous hydraulic cleaning.

Key words: energy dissipation rate; floc blanket; jet velocity; water treatment design

Introduction

Numerous books and journal articles have been published on water treatment facility design. Many of them provide guidelines for velocities, residence times and other relevant design parameters that are primarily based on studies of individual unit processes. Optimizing the design of a water treatment facility as an interconnected series of processes to balance performance and cost has not yet been possible because of an incomplete understanding of the interactions between unit processes. It is possible that many design parameters would change if the sequence of individual processes were optimized as a whole to reduce cost and produce the target treated water quality.
Floc blankets are fluidized beds of flocculating particles (flocs) that are created under upflow (as opposed to horizontal flow) conditions in a sedimentation basin. Ideal sedimentation tanks should provide efficient particle removal to achieve long runtimes for downstream filters while minimizing downtime for cleaning of the sedimentation tank. Floc blankets can provide improved particle removal without increasing the size of a sedimentation tank. Floc blankets have the added benefits of:
hydraulically eliminating sludge from the sedimentation tank without any moving parts
reducing biologically mediated gas production from settled solids
dissipating the momentum of the influent water and producing uniform vertical fluid velocities entering overlying plate settlers
enabling the construction of sedimentation basins that are less than 2 m deep.

Enhanced colloid capture in a floc blanket has been attributed to colloidal attachment to suspended flocs (Edzwald, 2011; Binnie and Kimber, 2013); however, the specific removal mechanisms have not been proven. Sustained operation of a flocculation/sedimentation treatment train with a floc blanket requires an understanding of conditions that may result in floc blanket failure and the ensuing high turbidity effluent. Failure to adequately operate a floc blanket is linked to pathogenic outbreaks (Logsdon, 2006). Therefore, improving the designs of water treatment facilities that employ floc blankets in the process train to ensure stable performance is desirable, as is an understanding of suitable operating conditions.
AguaClara is a program at Cornell University that researches, invents, and designs ultra low energy (15 J/L) municipal water treatment facilities that operate without the use of electricity. Sedimentation tanks designed by AguaClara (http://aguaclara.cornell.edu/implementation/design/) employ a sloped-bottom design that injects water into the bottom

*Corresponding author: School of Civil and Environmental Engineering, Cornell University, Hollister Hall, 220 Hollister Hall, Ithaca, NY 14853-3501. Phone: (607) 255-3438; Fax: (607) 255-9004; E-mail: cag266@cornell.edu {
Member of AEESP.

ENVIRONMENTAL ENGINEERING SCIENCE Volume 33, Number 2, 2016
ª Mary Ann Liebert, Inc.
DOI: 10.1089/ees.2015.0314

79

Downloaded by Cornell University package NERL from www.liebertpub.com at 07/08/19. For personal use only.

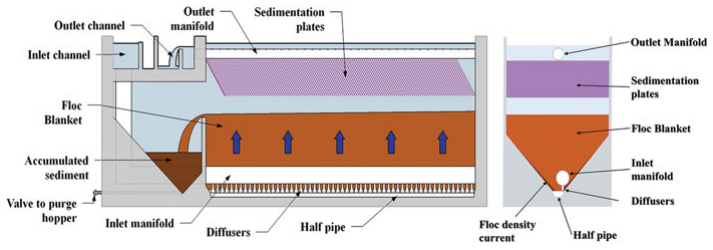
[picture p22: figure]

of the tank through a manifold that creates a line jet (Fig. 1). The sloped bottom allows settled flocs to form a floc density current and slide down to be resuspended by the incoming jet of flocculated water. If the momentum of the inlet jet is sufficient, the density current with a high concentration of flocs is returned to the floc blanket instead of accumulating as sludge in the bottom of the tank. This zero sludge design eliminates the need for mechanical sludge removal equipment. The AguaClara sedimentation tank can operate continuously by wasting excess floc blanket solids across a floc weir into a floc hopper. The floc hopper is drained periodically or continuously (while the sedimentation tank is still running) to remove consolidated solids.
Residence time, velocity through conduits, upflow velocity (surface loading rate), and velocity gradient are key parameters used for water treatment facility design. For conditions of turbulent flow, the energy dissipation rate (EDR) is a parameter that controls the floc aggregation rate and the maximum floc size (Cleasby, 1984). Evidence from tests of coupled flocculation, sedimentation systems is often lacking to justify suggested design parameters. It is not clear how individual processes can be modified to optimize the whole treatment process sequence. The 10 State Standards suggest avoiding an increase in velocity and velocity gradient between flocculation and sedimentation basins(Recommended Standards for Water Works, 2012) presumably to avoid breakup of flocs. In some sedimentation tank designs the inlet consists of a manifold of relatively small diameter orifices. If velocity is held constant, the EDR increases as the relevant length scale of the flow decreases [see Eq. (1) adapted from Baldyga et al. (1995)] and maintaining the same EDR as was used in the flocculator would require lower velocities in the inlet jets than in the flocculator. The EDR of the jet is given:
eJet ¼ ð | Þ PJetVJet

3

DJet

(1)

where eJet is the EDR (mW/kg of fluid mass), PJet = experimental coefficient dependent on jet parameters (round, plane, bounded, etc.), VJet is the velocity of the jet (m/s), and DJet is the diameter of the jet. According to the results compiled by Baldyga et al. (1995), PJet for an axisymmetric jet has a value of *0.5.
Other design guidelines and research suggest that use of higher EDR (a parameter closely related to the velocity gradient that describes the intensity of mixing) to create small, dense flocs would enhance removal in systems with direct filtration (Bache and Gregory, 2010; Edzwald, 2011; Binnie and Kimber, 2013). Therefore, conduits between flocculator and sedimentation unit processes could be smaller with high EDR without negatively impacting performance. Some studies have considered the impact of fluid shear on flocs but this parameter does not provide conclusive expectations as to whether plant performance would change. For example, if lamellar plate settlers are used above a floc blanket, flocs broken by an increase in EDR may still be large enough to be captured. Conversely, an increase in floc size does not necessarily imply an improvement in plant performance. The goal of water treatment is to produce low turbidity water, not to produce large flocs.
Design of entry conditions for flocculated suspensions into sedimentation tanks is commonly constrained to minimize breakage of flocs and, in the case of horizontal sedimentation tanks, to not scour settled sludge (Edzwald, 2011). However, resuspending settled flocs is necessary to build a floc blanket and provides a method to eliminate sludge accumulation in the sedimentation tank. Therefore, application of entry conditions suitable for horizontal sedimentation tanks to Agua-Clara systems or other upflow systems with floc blankets is likely not appropriate.
Biodegradation of accumulated sludge in sedimentation tanks can cause performance to worsen by releasing gaseous products that carry particles to the surface and thus elimination of settled sludge can improve particle removal efficiency. The ability of an inlet jet to resuspend the floc density current of settled flocs in an upflow sedimentation reactor with a floc blanket is dependent on the velocity of the incoming water. If settled flocs are not resuspended, the inlet jet region will fill and create a nonuniform distribution of flow. Retaining the EDR used in the flocculator in the sedimentation tank inlet jets results in much lower velocities that may not be able to resuspend the floc density current. The only specific recommendations available for inlet velocities for the sedimentation tank are for horizontal flow, flat-bottomed tanks. Since sludge will be removed by mechanical cleaners at the bottom of a horizontal sedimentation tank, design recommendations suggest an inlet jet velocity of 10–25 mm/s in basins 2.1–4.3 m deep so that settled sludge is not scoured (AWWA/ASCE, 2012).
The goal of the sloped bottom in the AguaClara sedimentation tank design is to return settled flocs to the inlet jet where they may be resuspended to facilitate rapid floc blanket growth. When the floc blanket design incorporates a floc hopper that harvests flocs at the floc water interface, excess flocs can be wasted hydraulically from the floc hopper. With flat-bottomed designs, the sedimentation tank has to be cleaned by mechanical submerged moving parts that are prone to failure or manually cleaned resulting in downtime.

FIG. 1. Schematic (front and side view) of the AguaClara Sedimentation Tank Design.

80 | GARLAND ET AL.

Downloaded by Cornell University package NERL from www.liebertpub.com at 07/08/19. For personal use only.

Design recommendations and prior research (Head et al., 1997; Sung et al., 2004; Chen et al., 2006) for sedimentation tanks are confined to flat-bottomed tanks. The AguaClara design seeks to maintain a continuous operation by resuspending all settled flocs and wasting the floc blanket at the floc water interface over a floc weir into a floc hopper.
One of the key parameters in the design of the AguaClara sedimentation tank is the velocity of the inlet jet and the goal of this research was to determine how this parameter influences settled effluent turbidity of a sequential flocculation, floc blanket, and lamellar sedimentation process. A range of sedimentation tank inlet jet EDRs were tested to determine the limits of failure. The hypothesis was that an increase of inlet jet EDR at the entrance to the sedimentation tank would result in floc breakup that would cause an increase in settled water turbidity at higher EDR and that decreasing jet EDR would eventually result in a failure to resuspend flocs. Operational behavior of the floc blanket was also observed and is discussed.

Experimental Protocol

The lab scale experimental apparatus was the same as described by Hurst et al. (2014) with the exception that a floc weir was used to limit floc blanket height and almost all influent fluid was removed from the reactor by passage through tube settlers. A schematic of the apparatus is provided in Fig. 2. Aerated tap water (average pH 7.36, total alkalinity 131 mg/L as CaCO3, total hardness 150 mg/L as CaCO3, dissolved organic carbon 1.83 mg/L, City of Ithaca, 2014) was mixed with an 8 gram/L stock kaolinite clay suspension (R.T. Vanderbilt Co., Inc. Norwalk, CT) to form a 100 Nephelometric Turbidity Unit (NTU) synthetic raw feed water. To maintain a steady influent suspended solids concentration, an in-line turbidity meter monitored the turbidity and proportional integral derivative (PID) control was used to meter the clay stock. Polyaluminum chloride (PACl) (PCH-180 Holland Co., Adams, MA) was mixed to create stocks of 1.0 gm/L or 1.7 gm/L as Al and added to the influent stream using a peristaltic pump. The flow rate of the pump was adjusted to obtain a PACl dose of 2.8 mg/L as Al to the influent during experiments.
Flocculation was achieved by a 121 m coiled tube flocculator (tube inner diameter of 9.5 mm, coil diameter of 130 mm). The EDR in the flocculator was calculated based on the head loss of a helically coiled tube using the Dean number (Tse et al., 2011). Two upflow velocities in the floc blanket were used for experiments, 1.2 and 1.6 mm/s, and were achieved by increasing the experimental flow through the flocculator. Table 1 shows hydraulic and mixing parameters in the flocculator for each upflow condition.
Capture velocity (also referred to as the critical velocity) of the tube settlers was set at 0.1 mm/s for both upflow velocities; an additional tube settler was used to remove additional flow in the higher upflow velocity condition. The EDR in the inlet portion of the sedimentation tank was changed by altering the diameter of the tube delivering flocculated water to the bottom of the tank.
To calculate maximum EDR for the jet, Equation (1) is used and PJet approximated to 0.23 by computational fluid dynamic simulation of 2-D jets. This value falls within experimental results of 0.23 for a plane, bounded jet (Haarhoff and Van Der Walt, 2001) and 0.5 for a round, free jet (Baldyga et al., 1995).
After the fluid exits the inlet jet tube, it travels around the jet reverser and begins to expand in the bottom of the tank. When the jet exits the tube the cross section of flow is circular. As the fluid travels around the jet reverser, it expands to the width of the experimental tank and becomes rectangular (Fig. 3). When the jet exits the reverser, it is a plane jet. Flow rate and velocity are conserved, so the crosssectional area of the flow remains the same such that Atube = APlaneJet. The smallest dimension of flow becomes the smallest dimension when the jet exits the reverser. The area of the plane jet is calculated:
APlaneJet ¼ STankWJet | (2)

where STank is the width of the tank (12.7 mm) and WJet is the width of the jet. DJet then becomes WJet in Equation (1) and is used in jet EDR calculations.
The range of tube diameters tested was 2.0–11.7 mm, which corresponded to maximum EDRs ranging from 0.25 to

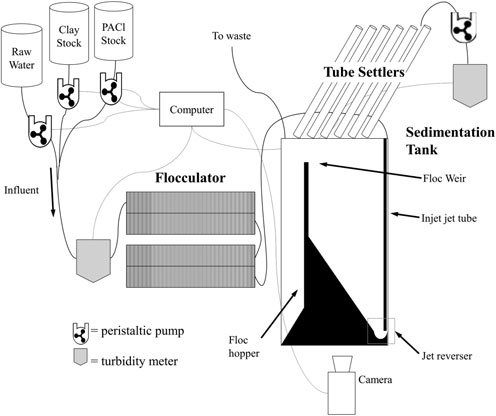
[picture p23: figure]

FIG. 2. Design schematic of experimental apparatus. Influent to the sedimentation tank from the flocculator entered through inlet jet tubes of variable size. The downward direction of the influent flow is redirected upward by the semicircular jet reverser bottom geometry. A small percentage of the flow insufficient to supply an additional tube settler was sent to waste.

Table 1. Flocculator Hydraulic Parameters

Under Experiment Conditions for 1.2 and 1.6 mm/s

Upflow Velocities Tested

Upflow velocity (mm/s)

| 1.2 | 1.6
Gh | 96,000 | 101,000
Flocculator Reynold’s Number | 815 | 1086
Flocculator head loss (m) | 0.74 | 1.1
Flocculator average energy dissipation rate, e (mW/kg) | 4.5 | 8.9
IMPACT OF INLET JET VELOCITY ON FLOC BLANKET FAILURE MODES | 81

Downloaded by Cornell University package NERL from www.liebertpub.com at 07/08/19. For personal use only.

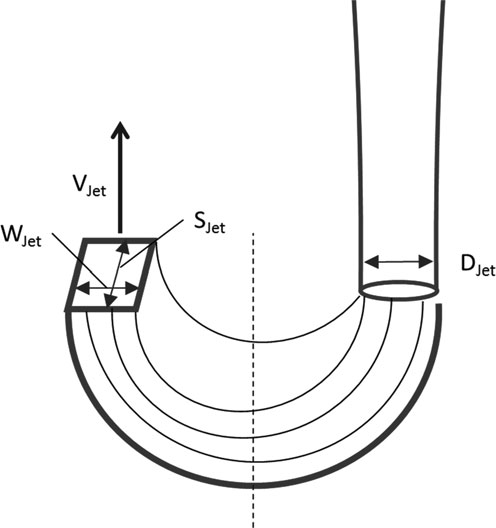
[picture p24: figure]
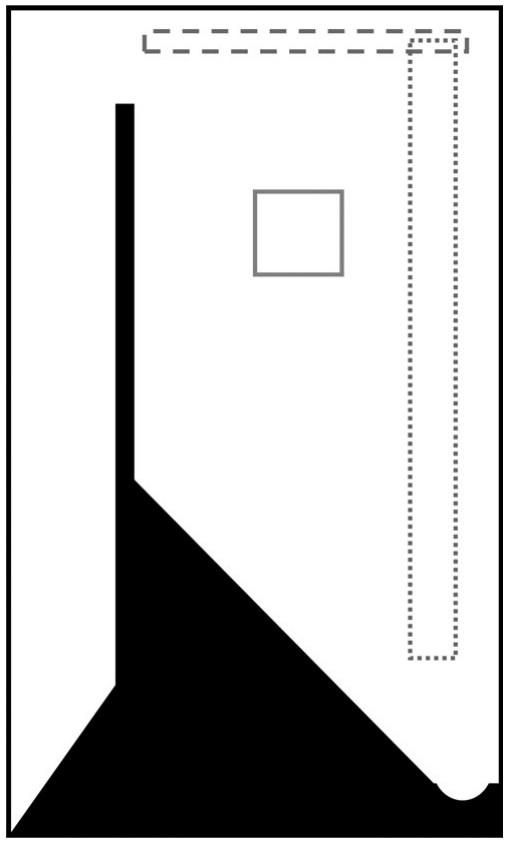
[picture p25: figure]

337,000 mW/kg (Fig. 4), an exit velocity that varied from 0.06 to 1.9 m/s and a calculated inlet jet tube shear head loss of 1.6 · 10⁻³
–8.4 m. The lowest velocity jet tested was more than double the maximum velocity recommended to prevent particle scour in horizontal sedimentation tanks (AWWA/ ASCE, 2012).
Images of the floc blanket were collected every 60 s with a Basler (Basler, Ahrensburg, Germany) color SCA640-70FC IEEE-1394B (658 X490 pixels) using an 8 mm lens. Effluent turbidity readings were collected at 5 s intervals for the duration of each experiment using an inline turbidity meter (HF Scientific Microtol Inline Turbidity Meter).
Visual regions of interest used for image analysis of blanket and supernatant (i.e., fluid above the floc water interface)

suspended solids concentrations are shown in Fig. 5 along with the region used to determine floc blanket height. Suspended solids concentrations were determined according to methods described by Hurst et al. (2014) based on absorbance of incident light.
Failure of the floc blanket tube settler system was defined as observation of an effluent turbidity in excess of 3 NTU (deemed to be an upper limit for water to be treated by filtration) or when the influent jet was unable to resuspend the floc density current coming from the sloped bottom into the jet reverser region. These failures cover conditions at the highest and lowest jet EDRs that would prevent the floc blanket sedimentation system from producing an acceptable quality of water.
System performance before a floc blanket was determined by extracting effluent turbidity data at one residence time of the entire system (referred to here as the experimental conditioning phase). The first full residence time (44 and 37 min for 1.2 and 1.6 mm/s upflow velocity, respectively) was required for the

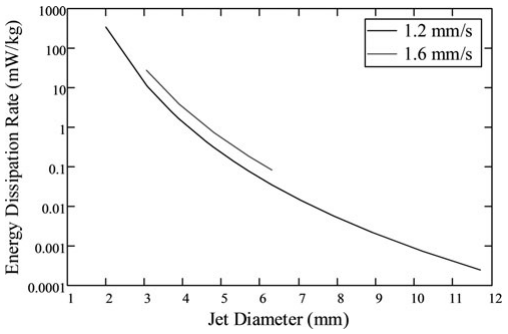
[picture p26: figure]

FIG. 4. Energy dissipation rates created by each jet diameter for upflow velocities of 1.2 and 1.6 mm/s.

FIG. 5. Regions of interest selected for image analysis of floc blanket (solid line), supernatant (long dashed line), and floc blanket height (short dashed line).

FIG. 3. Diagram of changing relevant flow dimensions in the jet reverser.

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

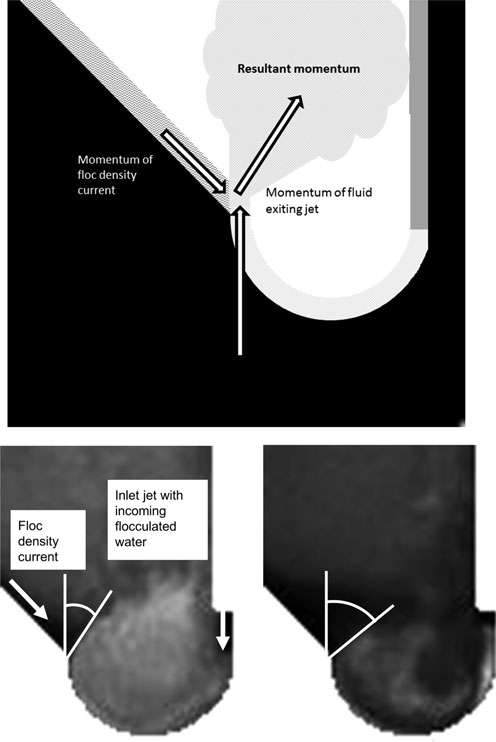
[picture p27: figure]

initial particle-free water in the experimental apparatus to exit the system. This time was sufficient for the first fluid packet of flocculated water to pass through the system and reach the effluent turbidity meter. Effluent turbidity detected at this point in time was not influenced by the presence of a floc blanket.

Results

A floc blanket formed for all experimental conditions tested. The total time required to form a blanket ranged from 3 h at the 1.6 mm/s upflow velocity to 5 h at the upflow velocity of 1.2 mm/s.
There were two potential failure modes of the system when changing the inlet jet EDR: (1) the effluent turbidity was greater than 3 NTU and (2) the jet was unable to resuspend the density current of settled flocs, allowing settled solids to fill in the inlet jet reverser. In the first failure mode, it is assumed that flocs were broken by the increased EDR to a size and quantity that could not be captured by the tube settlers or reformed in the floc blanket. The latter failure mode (accumulation of solids in the jet reverser region) would result in one or more of the following: uneven flow distribution in the tank because the inlet was occluded resulting in preferential flow through consolidating sludge in the jet region, and the inability for complete resuspension of settled solids needed to support continuous operation.
During experimentation, the fluid exiting the inlet jet tube traveled in a semi-circular flow through the bottom geometry (referred to here as the jet reverser) and mixed with the incoming floc density current. The upward vertical momentum of the jet exiting the reverser region must be higher than the downward momentum of the incoming floc density current to prevent accumulation of flocs. The balance between the momentum of the jet and floc density current was reflected in the angle between the floc density current and the upward jet (Fig. 6). As the inlet jet diameter increased (EDR decreased) and mass flow rate remained constant, jet velocity decreased causing the momentum of the incoming flow to decrease. Since momentum of the jet decreased as jet diameter increased and the floc density current did not change considerably, the downward momentum of the floc density current eventually exceeded the upward momentum of the inlet jet leading to failure. Thus, at failure there was insufficient vertical momentum to carry the settled flocs back up into the floc blanket (Fig. 6).

Blanket, supernatant, and effluent concentrations
for floc blankets at steady state

Floc blanket concentration in the sedimentation tank reached a steady value before the floc blanket reached the floc weir. Once the floc blanket developed a clear floc water interface and started growing in height, the floc blanket stayed at approximately the same suspended solids concentration for the rest of the experiment. The floc blanket grew to the height of the floc weir and then maintained a constant height by wasting over the floc weir.
Figure 7 provides an example run with images at times when the system is changing or at steady state. Once the system completed the conditioning phase (i.e., after one fluid residence time), the supernatant suspended solids concentration and effluent turbidity increased dramatically and then decreased as the floc water interface became apparent and the height of the floc blanket started increasing. The supernatant concentration steadily rose after the floc blanket developed and grew in height while the effluent turbidity steadily decreased. Once the floc blanket reached the floc weir and started wasting to the floc hopper, it was considered to be at steady state as the height was fixed and the floc blanket concentration remained the same.
For the range of EDR tested (excluding failures at the highest and lowest EDR), the average floc blanket concentration was 1,608 mg/L (r = 294 mg/L) at the 1.2 mm/s upflow velocity and 1,145 mg/L (r = 218 mg/L) at the 1.6 mm/s upflow velocity. Average supernatant concentrations were 193 mg/L (r = 59 mg/L) and 159 mg/L (r = 82 mg/L) for 1.2 and 1.6 mm/s, respectively. Average effluent turbidities were 0.74 NTU (r = 0.67 NTU) and 0.72 NTU (r = 0.92 NTU). Coefficient of variation for steady state floc blanket concentrations was 0.18 and 0.19 for 1.2 and 1.6 mm/s, respectively. Steady state concentrations for all locations monitored are presented in Fig. 8. At thelargest jet EDR tested (337,000 mW/ kg and 27,300 for 1.6 mm/s), the effluent turbidity was above 3

FIG. 6. Close-up of the confluence of the floc density current and the upward jet at steady state for 7.05 mm (left) and 8.9 mm (right) jet diameters. The angle of jet interaction with the density current (indicated with a superimposed line) increased as the jet velocity decreased leading to failure for low momentum jets.

IMPACT OF INLET JET VELOCITY ON FLOC BLANKET FAILURE MODES | 83

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

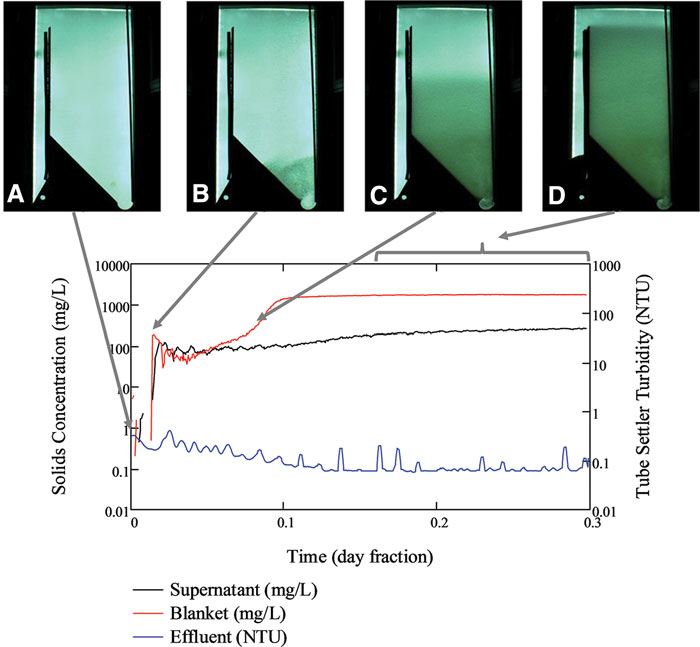
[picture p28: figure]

NTU resulting in system failure. The results reveal a steady increase in effluent turbidity beginning at *300 mW/kg before the system reached failure. In this region after the effluent turbidity begins to increase and before failure, it is expected that some flocs were broken and system performance was adversely affected by the high EDR in the influent jet. System failure occurred at the lowest EDR tested at 1.2 mm/s (0.25 mW/kg) as the jet reverser began to fill in with the floc density current. Failure to resuspend settled flocs did not occur for any EDR tested at the 1.6 mm/s upflow velocity. Figure 9 shows an example of the system when the jet reverser is adequately cleared (left photo) and when it is being filled in (right photo).

Performance with and without floc blanket

Overall floc blanket performance was defined in terms of the negative logarithm of the ratio of solids concentration in the effluent and influent (pC*) [Eq. (3)]. High values of pC* correspond to improved performance.

pC ¼ log CEffluent

CInfluent -

| (3)

In all experiments, system performance increased in the presence of a floc blanket (Figs. 10 and 11), however, a smaller change in performance is noted at the extremes of inlet jet EDR for 1.2 mm/s. Performance with a floc blanket improved by an average of 0.9 pC* (i.e., an eight-fold decrease in effluent turbidity) across all EDRs not in failure at an upflow velocity of 1.2 mm/s and 0.4 pC* (2.5-fold decrease in effluent turbidity) for 1.6 mm/s upflow velocity.

Discussion

The effluent suspended solids concentration remained unaffected by inlet jet EDR until about 300 mW/kg and decreased below acceptable performance at 6,000 mW/kg as interpolated from Fig. 9. Based on this information, inlet jet EDR could be increased above that in current design guidelines without decreasing plant performance. Previous guidelines limit inlet velocity gradient (more correctly the EDR) to less than or equal to equivalent flocculator velocity gradient (Hudson 1981). This research has shown that when a floc blanket and lamellar settlers follow the flocculator, overall performance begins to decrease when the sedimentation tank inlet has an EDR that is greater than 60 times the EDR of the flocculator in the 1.2 mm/s case and 63 times greater in the 1.6 mm/s case (Fig. 8). Given that performance is still acceptable at higher jet EDR, smaller inlet jets with a higher velocity can be used to ensure the inlet jet is able to resuspend the floc density current and to decrease the required size of inlet manifolds.
Design guidelines suggest that flocs would have been broken to some degree in any EDR that exceeded the flocculator EDR. Given that deterioration in system performance was not observed until the inlet jet EDR was much higher than the flocculator (*60 times higher for 1.2 mm/s and *63 times higher for 1.6 mm/s), the system can perform well with a higher inlet jet EDR. If flocs are indeed broken at an EDR that exceeds the flocculator EDR, then (1) the tube settler capture velocity was sufficient to capture the smaller flocs or
(2) the floc fragments were captured in the floc blanket. Only at an EDR >300 mW/kg did the effluent turbidity begin to increase. A closer analysis of EDR gradient in the

FIG. 7. Example experimental run with images at notable times.
(A) is just after the system is started and marks the beginning of the conditioning phase. (B) is when the conditioning phase is complete and the supernatant and effluent turbidity spike. (C) is just after the floc blanket has passed through the blanket regions of interest. (D) is the tank at steady state after the floc blanket has reached the floc weir.

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

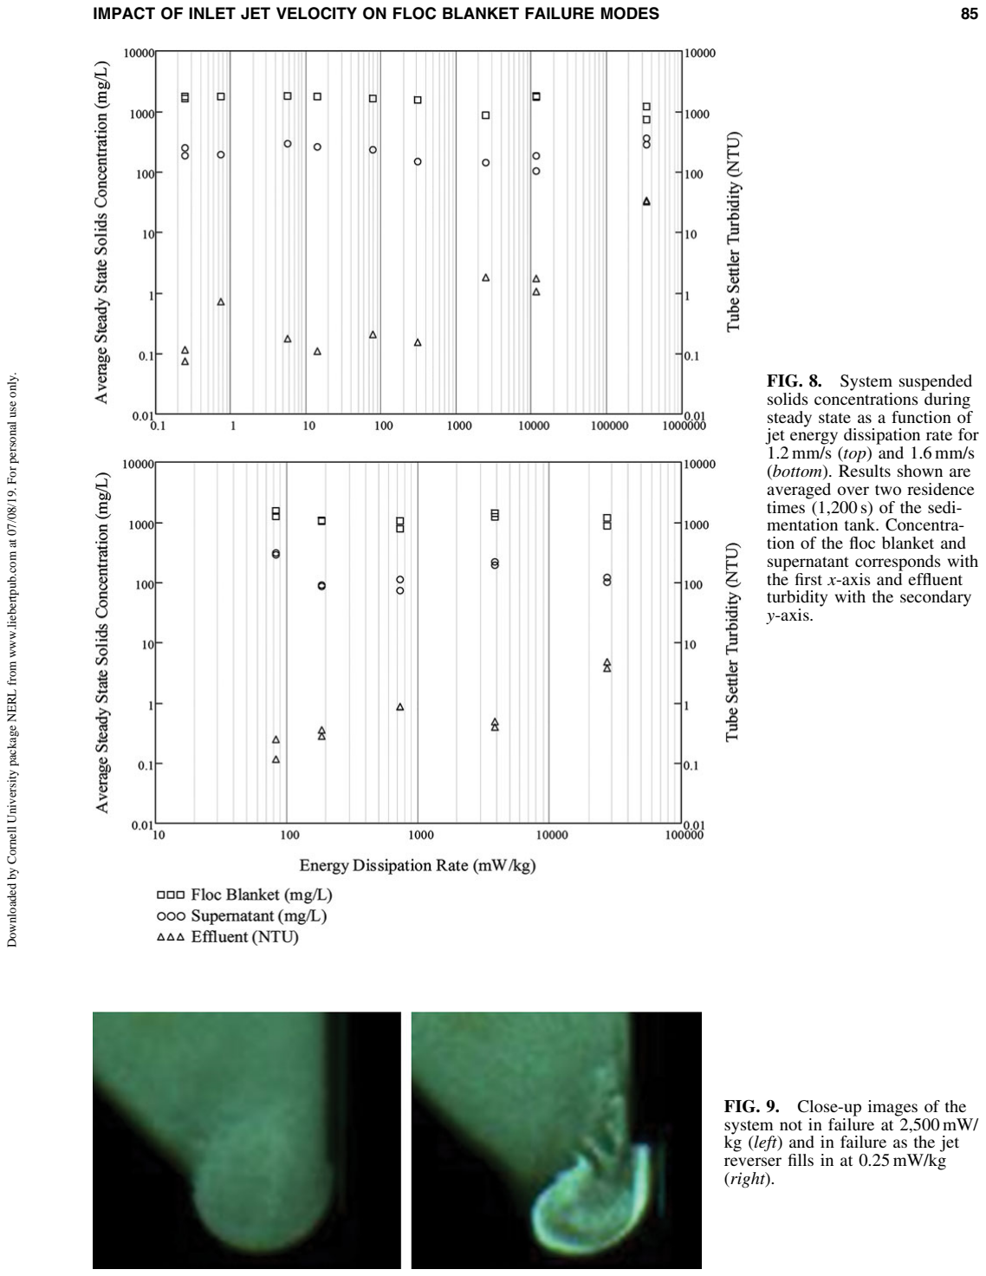
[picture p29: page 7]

FIG. 8. System suspended
solids concentrations during steady state as a function of jet energy dissipation rate for 1.2 mm/s (top) and 1.6 mm/s (bottom). Results shown are averaged over two residence times (1,200 s) of the sedimentation tank. Concentration of the floc blanket and supernatant corresponds with the first x-axis and effluent turbidity with the secondary y-axis.

FIG. 9. Close-up images of the system not in failure at 2,500 mW/ kg (left) and in failure as the jet reverser fills in at 0.25 mW/kg (right).

IMPACT OF INLET JET VELOCITY ON FLOC BLANKET FAILURE MODES | 85

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

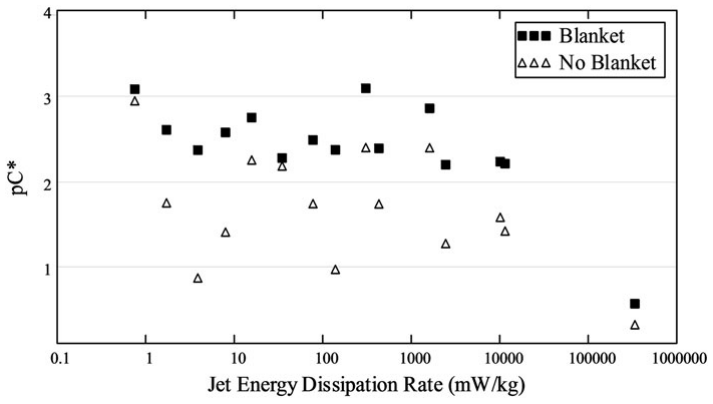
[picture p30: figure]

sedimentation tank influent jet would be needed to determine the actual size of the region where the maximum EDR is obtained.

Summaries

Based on the experimental results, inlet jets for floc blanket sedimentation systems could be designed at higher EDR and thus higher velocities to ensure floc density current resuspension without negatively impacting the effluent water quality. For the AguaClara design, a suggested EDR upper limit for the inlet jet is 300 mW/kg. For a 1 m wide sedimentation tank and an upflow velocity of 1 mm/s this corresponds to a velocity of 340 mm/s. At this velocity the minor head loss at the exit of the plane jet is 6 mm and that should be taken into account in the hydraulic design. It is important to note that average velocity gradient is not an appropriate design parameter for the flow passages between the flocculator and sedimentation tank if the goal is to prevent excessive breakup of flocs because flocs are broken by the maximum EDR they experience and the EDR is a function of the flow geometry and the velocity. In comparison to recommended values for inlet velocities of 10–25 mm/s (AWWA/ASCE, 2012), the results of this research suggest up to 340 mm/s is permissible for a

1.5 mm thick plane jet before a change in performance is apparent in the system. It is apparent that general water treatment plant design guidelines do not apply to the AguaClara system or by inference to other upflow sedimentation reactors with floc blankets, and suggest that design parameters could be reevaluated to optimize performance.
Only at extremely high inlet jet EDR did the experimental system produce an unacceptable water quality. At the lower end of EDR range tested, the jet was unable to resuspend the returning floc density current and led to sludge accumulation. In a full scale system, biodegradation of accumulated sludge could result in gas production; and dissolved gas flotation of flocs to the top of the sedimentation tank. To resuspend the floc density current, a minimum jet velocity of 75 mm/s is suggested for the given system and lab conditions. The inability of a jet to resuspend the floc density current could be better characterized by determining the momentum of the two flows (floc density current and inlet jet). Further research to determine the minimum inlet jet requirements to suspend the floc density current should be based on momentum to accommodate the changing flocculated water momentum and floc density current concentrations. The results of this research indicate that AWWA and 10 State Standard design guidelines for upflow sedimentation tank inlets such as the AguaClara design is not useful.

FIG. 10. System performance with and without floc blanket at upflow velocity of 1.2 mm/s

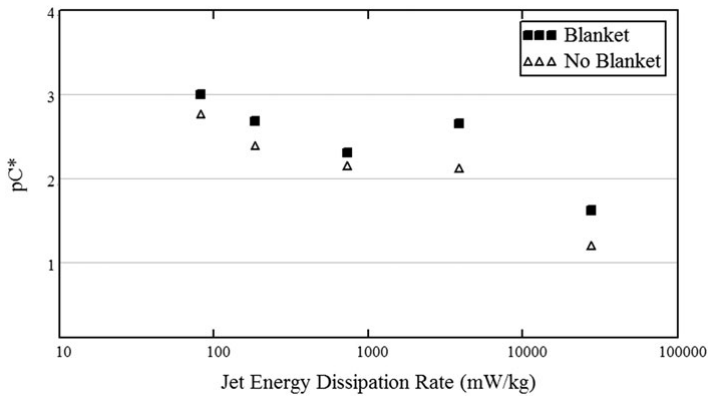
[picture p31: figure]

FIG. 11. System performance with and without floc blanket at upflow velocity of 1.6 mm/s

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

Increasing inlet jet EDR reduces conduit size without significantly changing particle removal efficiency. Since smaller conduits are less expensive, plant construction costs are less. There is ultimately a limit to the EDR that can be applied to a flocculated suspension before performance decreases in the system. However, there is a region before this limit where flocs appear to be broken into smaller aggregates that can still be captured by lamellar sedimentation where there is no decrease in performance. It is uncertain which mechanism (particle capture by the floc blanket or tube settlers) achieves the removal of broken flocs and further investigation into the removal of flocs and colloidal particles in a floc blanket system is needed. This information with additional research into the mechanistic interaction of the inlet jet flow with the floc density current could provide more definitive design guidelines based on a physical understanding of floc-shear interactions (rather than empirical) for both AguaClara and other sedimentation tanks.

Acknowledgment

This research was supported, in part, by National Science Foundation award ID 1437961.

Author Disclosure Statement

No competing financial interests exist

References

AWWA/ASCE. (2012). Water Treatment Plant Design (5th ed.). American Water Works Association & American Society of Civil Engineers, New York: McGraw-Hill Professional Publishing.
Bache, D.H., and Gregory, R. (2010). Flocs and separation processes in drinking water treatment: a review. J. Water Supply Res. Techno. AQUA. 59, 16.
Baldyga, J., Bourne, J.R., and Gholap, R.V. (1995). The influence of viscosity on mixing in jet reactors. Chem. Eng. Sci. 50, 1877.

Binnie, C., and Kimber, M. (2013). Basic Water Treatment (5th ed.). The Royal Society of Chemistry, London: ICE Publishing.
Chen, L, Lee, D., and Chou, S. (2006) Charge reversal effect on blanket in full-scale floc blanket clarifier. J. Environ. Eng. 132, 1523.
Cleasby, J.L. (1984). Is velocity gradient a valid turbulent flocculation parameter? J. Environ. Eng.. 110, 875.
Cornell University Water System. (2014). Drinking Water Quality Report. Technical Report. Ithaca, New York. Edzwald, J.K. (2011). Water Quality & Treatment: A Handbook on Drinking Water (6th ed.). New York: McGraw-Hill. Available at: http://accessengineeringlibrary.com.proxy.library.cornell.edu/browse/water-quality-and-treatment-a-handbookon-drinking-water-sixth-edition (accessed July 17, 2015) Haarhoff, J., and Van Der Walt, J.J. (2001). Towards optimal design parameters for around-the-end hydraulic flocculators. J Water Supply Res Technol. AQUA. 50, 149.
Head, R., Hart, J., and Graham, N. (1997). Simulating the effect of blanket characteristics on the floc blanket clarification process. Water Sci. Technol. 36, 77.
Hudson, H.E. (1981). Water Clarification Process: Practical Design and Evaluation. Van Nostrand Reinhold, New York. Hurst, M., Weber-shirk, M., Charles, P., and Lion, L.W. (2014). Apparatus for Observation and Analysis of Floc Blanket Formation and Performance. J. Environ. Eng. 140, 11. Logsdon, G.S. (2006). How Waterborne Disease Outbreaks Relate to Treatment Failures. Association of Environmental Engineering & Science Professors. Retrieved from http://www.aeespfoundation.org/publications/pdf/AEESP_CS_3.pdf Recommended Standards for Water Works. (2012). Great Lakes
- Upper Mississippi River Board of State and Provincial Public Health and Environmental Managers, Albany, NY. Sung, S., Lin, W., Chen, L., and Lee, D. (2004). Spatial stability of floc blanket in full-scale floc blanket clarifiers. J. Environ. Eng. 130, 1481.
Tse, I.C., Swetland, K., Weber-Shirk, M.L., and Lion, L.W. (2011). Method for quantitative analysis of flocculation performance. Water Res. 45, 3075.
IMPACT OF INLET JET VELOCITY ON FLOC BLANKET FAILURE MODES | 87

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

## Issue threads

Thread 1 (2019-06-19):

Running Task List: Setting Up Sensors at Water Treatment Plant

IanCullings, 2019-06-19:
[ ] - Connect ethernet to sensors - Need IT man
[ ] - Clean turbidimeter
[ ] - Figure out problem with the power source for Organics Sensor

IanCullings, 2019-06-21:
[ ] - Do math for flocculator baffles redesign
[ ] - Connect cables and water flow line to sensor table
[ ] - Install safety equipment at CWFP
[ ] - Design and connect new pipe system to raise water level (Drain Plantita)
[ ] - Pipe all outlets to outflow drain
[ ] - Run tests and collect data!

IanCullings, 2019-06-24:
Other random tasks:
- [ ] Look over and update OnShape
- [ ] Write research report for full documentation

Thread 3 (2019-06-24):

Floc Hopper Measurement

IanCullings, 2019-06-24:
Floc Hopper Pump Idea;
* Use LED and voltage sensor connected to procoda to run waste pump.  Calibrate to value between clear and totally obscure
* Collect data on pump flow rate to get a sense for the ideal outflow rate in PF300's in the field

IanCullings, 2019-06-24:
For floc blanket formation rate, assume rate is linear and measure visually when flocs begin to leave through the floc hopper.  Can also connect top valve from side of 1LPS to the second particle counter and collect data to have a time stamp (and more data on particle size from the top of the floc blanket?)

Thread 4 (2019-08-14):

Research Report Comments

ChingPangggg, 2019-08-14:
Hi guys! I am very sorry for the delay, but I have made a couple light edits to the report and here are my comments! Please let me know if I was being unclear :) Here[https://github.com/AguaClara/Prefabricated-Pilot-Plant/blob/master/Summer2019_Report_2.ipynb] is the link to the report that I edited
Introduction:
Very clear, but try to keep the tense consistent and I would suggest combining the two text blocks or title the second text block as previous work

Methods:
You can delete the instructions for methods
Reorganize the levels of titles in project one and project two here (number of #)

Project One:
- Keep the use of tense consistent
- Include where you purchase the sensors and materials, so that future teams have a reference
- Figure one is missing
- when taking about previous work, you can just use last name and add a link for reference (e.g. Garland (2018), instead of Casey Garland)
- What is the design floc blanket height
- Maybe include screenshot from the video too?
- You mentioned turbidimeter, and past semester did not capture the small particles, but you never connected the two
- Try to avoid using this and say the specifics (e.g. This only occurs when the floc blanket begins to grow, what is this in this case)
-  where is the rangefinder pictured below
- avoid using first person
- define too turbid
- "Research is ongoing..." again, what is "this", connect the sentence with the last paragraph if you mean the slope here

Project Two:
- Avoid using too many pronouns
- Keep the use of tense consistent
- Include were to purchase the materials (with links) for future references
- avoid using first person, can use passive voice
- (figure 4) what is the ratio of the different diameters here?
- Remember to include pipe size

Project Three:
- what should be under flocculator and sed tank?
- keep the tense consistent
- what lead you to conclude that there is an escape of sand
- picture would be helpful here

Future Work:
- More justification for this (e. g. summarizing what the challenges encountered were etc)
- consistent use of tense would be great

Bibliography:
- You have used more than one reference in this report so try to put them all up

In addition to the comments, I think it would be helpful if you can organize your repository by semesters!
It would be great if you can send me a final version of the report by Aug 20 (Tues) and remember to update your readme!

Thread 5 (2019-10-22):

Short term goals

tm545, 2019-10-22:
Hi guys great meeting today, I think we have a clear direction moving forward for now and maybe adding some goals to have done that can help you out with how to distribute work. I want to try something Matt used to do with his subteams. I'll outline an agenda with some expected goals and some reach goals I think would work. This is the first attempt so if you miss some expected goals I think that's fine and I'm really just shooting in the dark here and I'm not sure about your schedules or available times right now.

**Expected Goals:**

- Stress analysis of filter box
- Stress analysis of the filter outlets
   - Ensure that push to connects can withstand the flow through them without tubing bursting off
   - Look at pressure that backwash puts on the exit pipe to better understand stress put on the exits

**Reach Goals:**
- Decide on Material to order and place orders on McMaster-Carr
- Figure out what input the CNC needs to make our exit stencil
- Make that CNC input (my gut is saying it would be a CAD file but we would have to check)

Let me know what you guys think of this and what would be a good time you think this should be done by.
Peace out
Girl Scout

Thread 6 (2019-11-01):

CAD for new filter flow channel design

nwangg, 2019-11-01:
[Onshape File](https://cad.onshape.com/documents/5b4907bb2848688cd4593a1c/w/b4a87f009f8969e3e0343c5e/e/7a5d5497b447d03dbb70a5b6)

The above linked document has the parametrizable CAD model for the 'tick' design of the flow channel.
The design is basically complete except for needing to add holes and a slight issue with the calculation of the height of the tick body in relation to the spacing of the gravity exclusion zones (referred to as 'legs' in the configurations).

The spacing between the gravity exclusion zones is set as : (sin(30 deg)/sin(#beta))*(#leg_length+#tick_leg_t), where 30 degrees is the angle of the 'legs' such that sand will slide down by itself, beta being the angles at the top of the body.
The diagonal length of the body is then defined by ((sin(30 deg)/sin(#beta))*(#leg_length-#tick_leg_t/(#leg_n-1))+#tick_leg_t)*(#leg_n-1)+#tick_leg_t
However, the bottom of the bottom leg does not line up with the bottom of the body, and we are unable to figure out where the math went wrong.

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

nwangg, 2019-11-01:
@monroews @marcin-sawczuk

monroews, 2019-11-01:
Given that the overall width of the system is a real constraint (so that backwash works well) and given that the only reason for the trapezoidal center section is to help solve a failure mode that will hopefully not be a problem, and given that the flow area of the center section likely ends up being much larger than needed, I propose that the center section be turned into a rectangle. The cross sectional area of the center section can be estimated from [manifold analysis](https://aguaclara.github.io/Textbook/Hydraulics/Hydraulics_Intro.html#equation-manifold-max-v-no-hl-series). The orifices would presumably have a contracted velocity that corresponds to a head loss of about 5 cm. (head loss = v^2/(2g) where v is the contracted velocity which is also required for the manifold design.

I'm guessing that if you revert to a simple rectangular cross section the design will be simpler, the alignment error will go away, and you will be able to design the width of the rectangle using the manifold equation.

monroews, 2019-11-04:
This looks great. Do you have an algorithm for calculating the hole diameter and spacing?

marcin-sawczuk, 2019-11-04:
Hi,
3 days ago I wrote a reply to this issue, but somehow it wasn't posted...

In general, I think that this misalignment does no matter. Our printer will barely see it at wall thickness of 2 mm. I'd say that you should work on spacing the holes and get this thing printed. Do you know how tall can we print on our 3D printer?

Regarding the reason for the misalignment - it happens because the bottom wall thickness is measured at 90deg and the roof thickness at 60deg. There is no way they can be aligned. If you want it to look nicely, you should either extend the bottom of the roof or draw the geometry with single lines and convert them to the walls using Slot option (setting slot thickness to 2 mm).

Let me know if that helps:)

Br.,
Marcin Sawczuk

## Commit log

2019-06-11 Add Honduras autocad and fabrication manual
    [autocad_honduras_1.dwg]
2019-06-12 Add user manual for sensor data
2019-06-25 Update with Methods for Sensor Setup
2019-08-02 filter connections image
2019-10-22 Schedule first draft
    [PF200 schedule.xlsx]
